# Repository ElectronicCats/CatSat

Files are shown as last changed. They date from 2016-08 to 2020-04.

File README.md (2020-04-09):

# CatSat I

OSHW

**[OSHW] MX0004 | Certified open source hardware |** [oshwa.org/cert.](https://www.oshwa.org/cert)

## Kit CatSat Education

Manual and more information in our [Wiki](https://github.com/ElectronicsCats/CatSat/wiki)

Electronic Cats invests time and resources providing this open source design, please support Electronic Cats and open-source hardware by purchasing products from Electronic Cats!

<a href="https://electroniccats.com/store/catsat/">
  
</a>

Designed by Electronic Cats.

Firmware released under an GNU AGPL v3.0 license. See the LICENSE file for more information.

Hardware released under an CERN Open Hardware Licence v1.2. See the LICENSE_HARDWARE file for more information.

Electronic Cats is a registered trademark, please do not use if you sell these PCBs.

16 July 2016

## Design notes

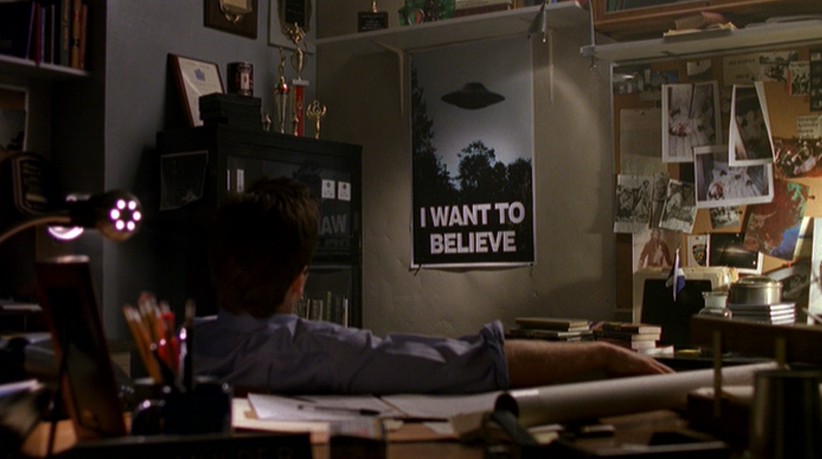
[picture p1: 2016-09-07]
PDF's/MulderNewPoster.jpg

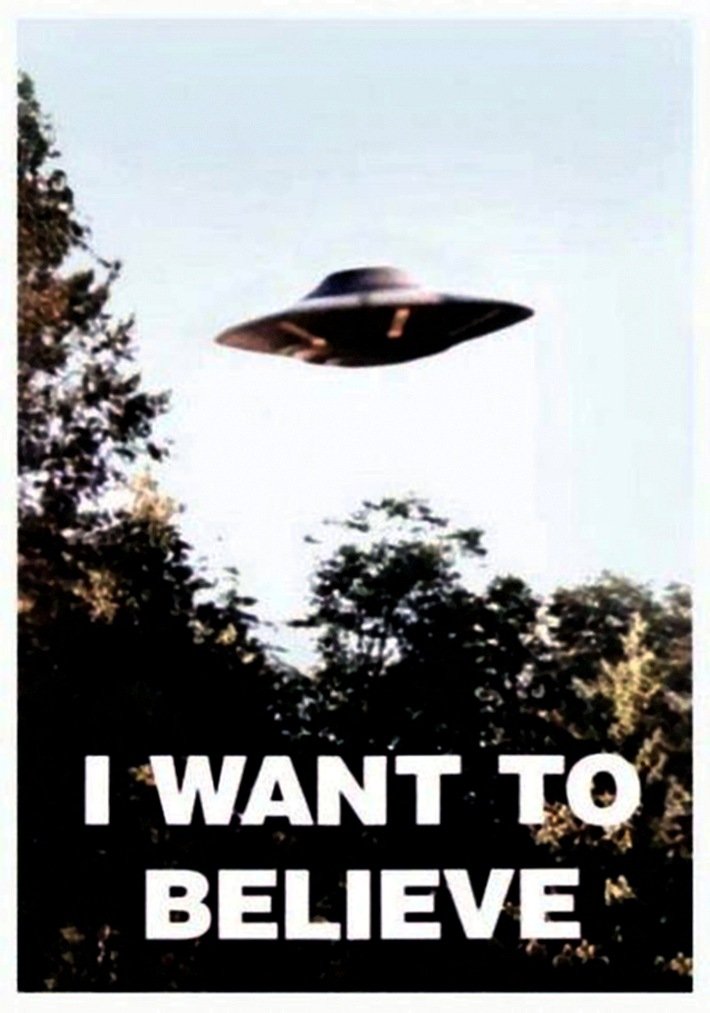
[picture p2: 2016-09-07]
PDF's/xfiles.jpg

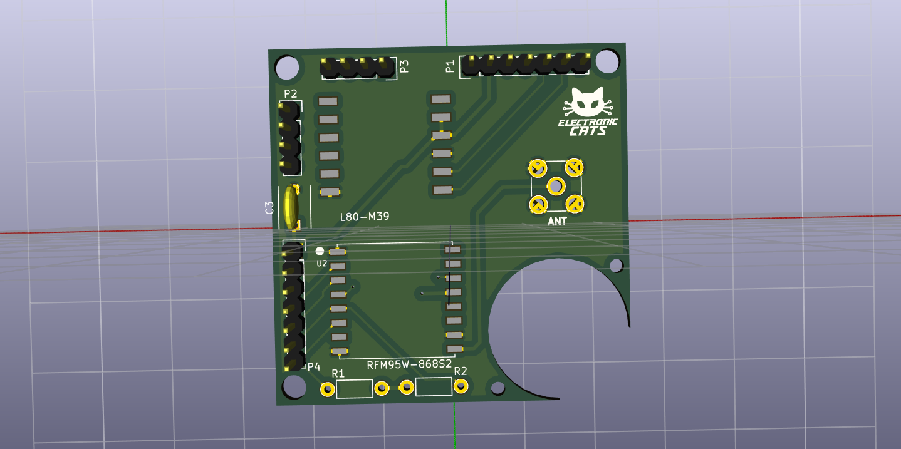
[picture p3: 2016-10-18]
CommunicationBoard/CommunicationBoard.png

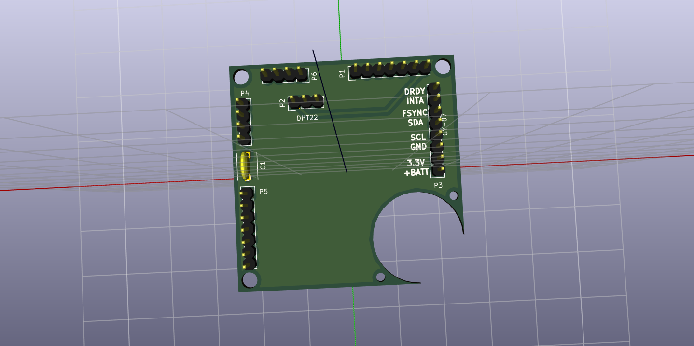
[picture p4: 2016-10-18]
SensorBoard/SensorBoard.png

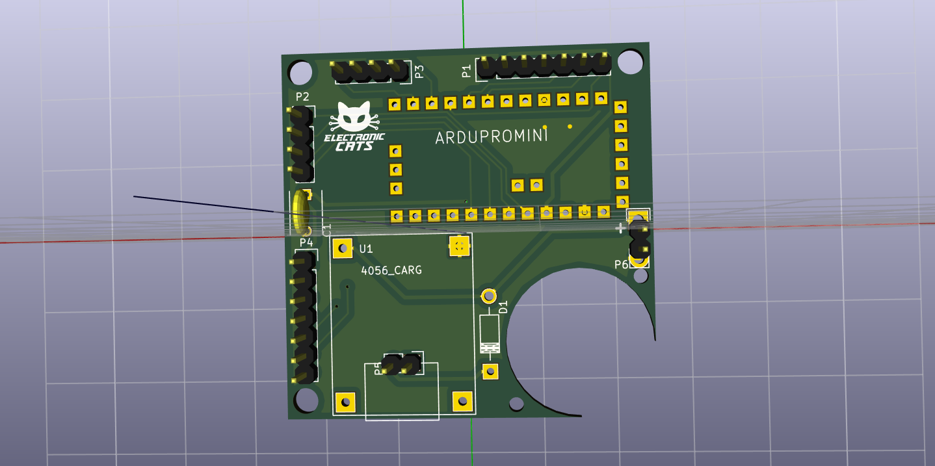
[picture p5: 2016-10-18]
MainBoard/MainBoard.png

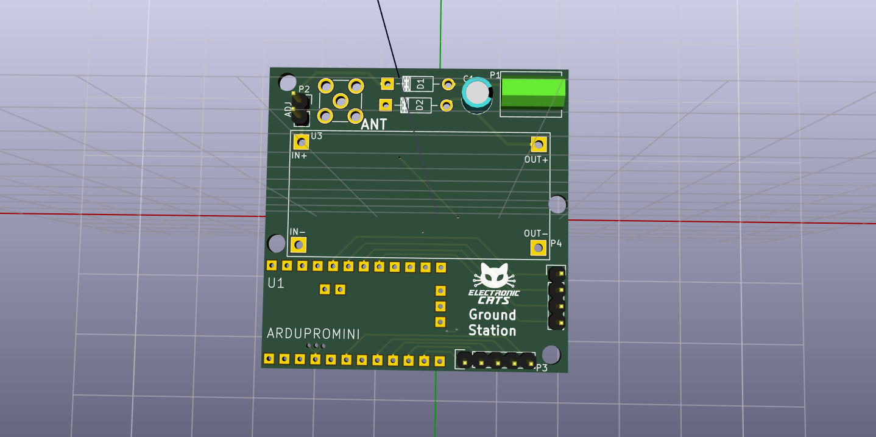
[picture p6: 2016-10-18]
GroundStation/GroundStation.png

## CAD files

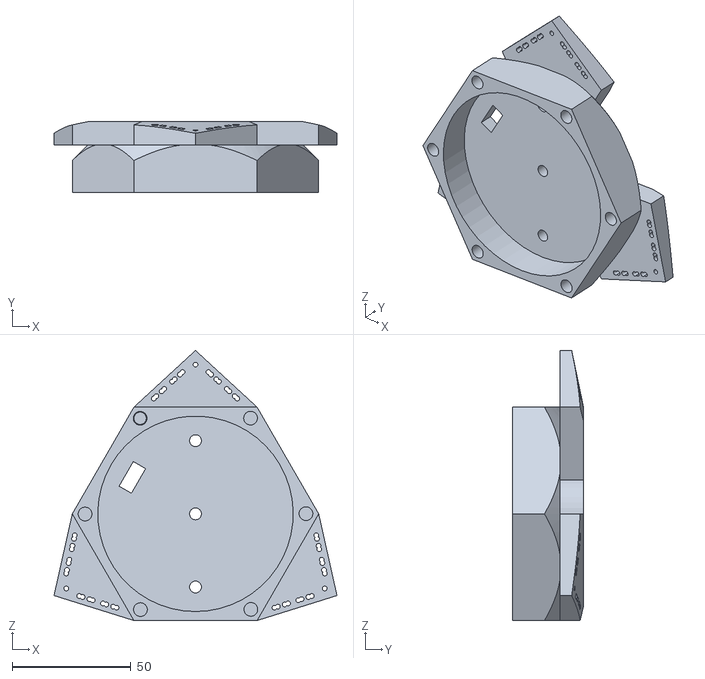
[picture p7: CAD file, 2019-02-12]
caseCatSat1/tapasuperior.STL
119.4 x 30.0 x 113.9

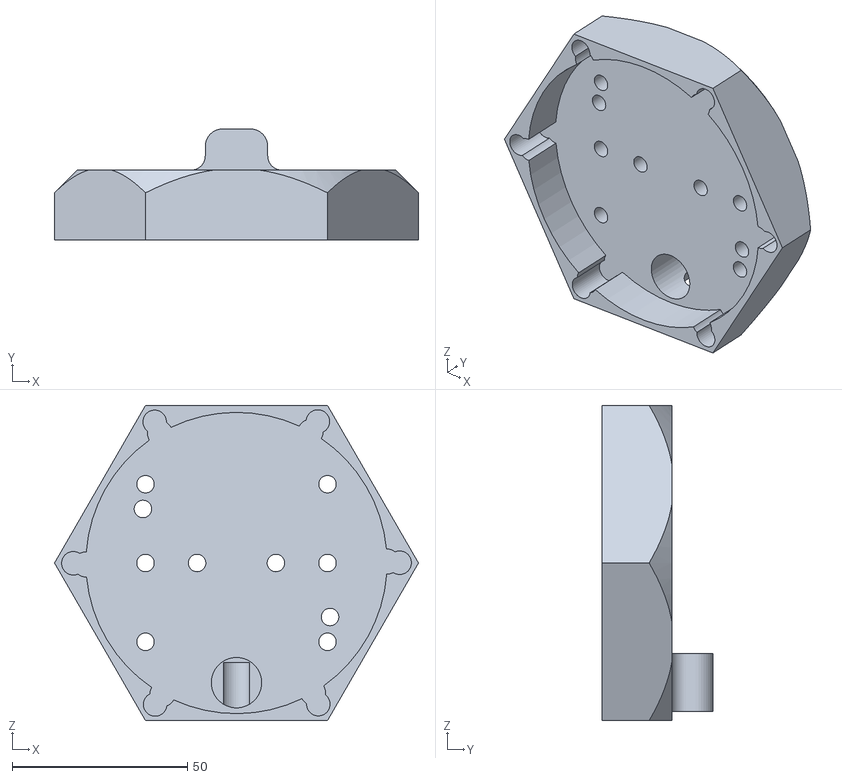
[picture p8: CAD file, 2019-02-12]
caseCatSat1/tapainferior.STL
103.9 x 31.8 x 90.0

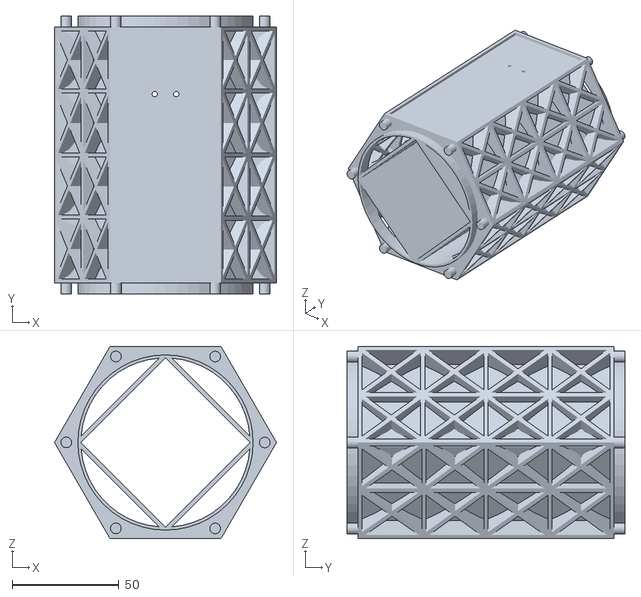
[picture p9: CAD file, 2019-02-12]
caseCatSat1/satelite2.2.STL
103.9 x 130.0 x 90.0

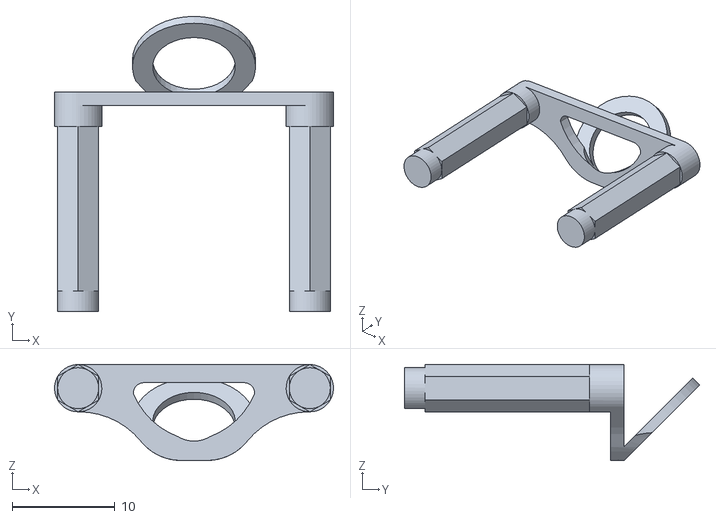
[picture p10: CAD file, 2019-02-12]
caseCatSat1/camarasuport.STL
27.1 x 28.7 x 9.32

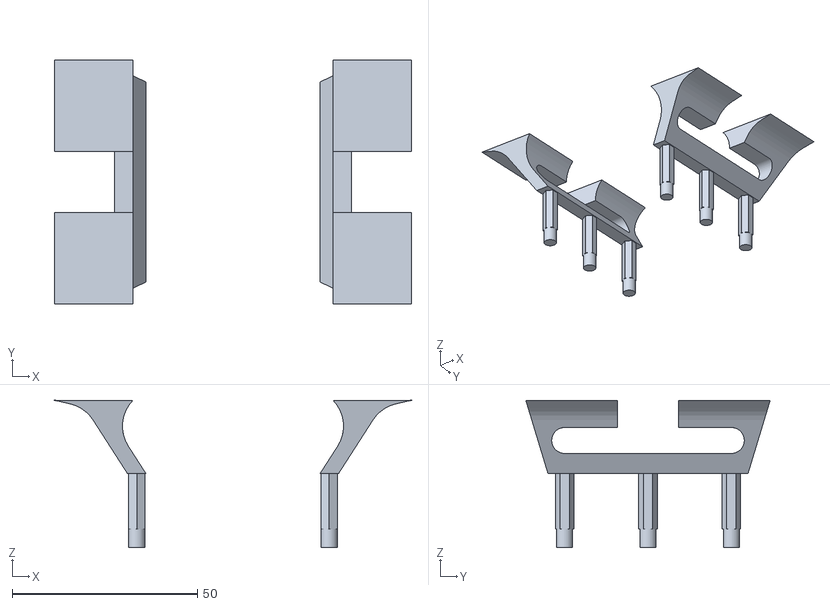
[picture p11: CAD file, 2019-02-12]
caseCatSat1/base.STL
96.4 x 66.0 x 39.8

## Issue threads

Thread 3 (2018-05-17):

Corrección de texto en Wiki

carlosmart7104, 2018-05-17:
04. Vida de la Misión. 4.4 Recuperación, en la frase: "El ingeniero de Sistemas Espaciales deberá disponer de un equipo de recuperación en base a la última información de rastreo emitida por el CanSat..."
Propuesta:
"El ingeniero de Sistemas Espaciales deberá disponer de un equipo de recuperación con base en la última información de rastreo emitida por el CanSat..."
http://www.academia.org.mx/espin/respuestas/item/con-base-en

sabas1080, 2018-08-14:
Muchas gracias @carlosmart7104 , corregido

Closed 2018-08-14.

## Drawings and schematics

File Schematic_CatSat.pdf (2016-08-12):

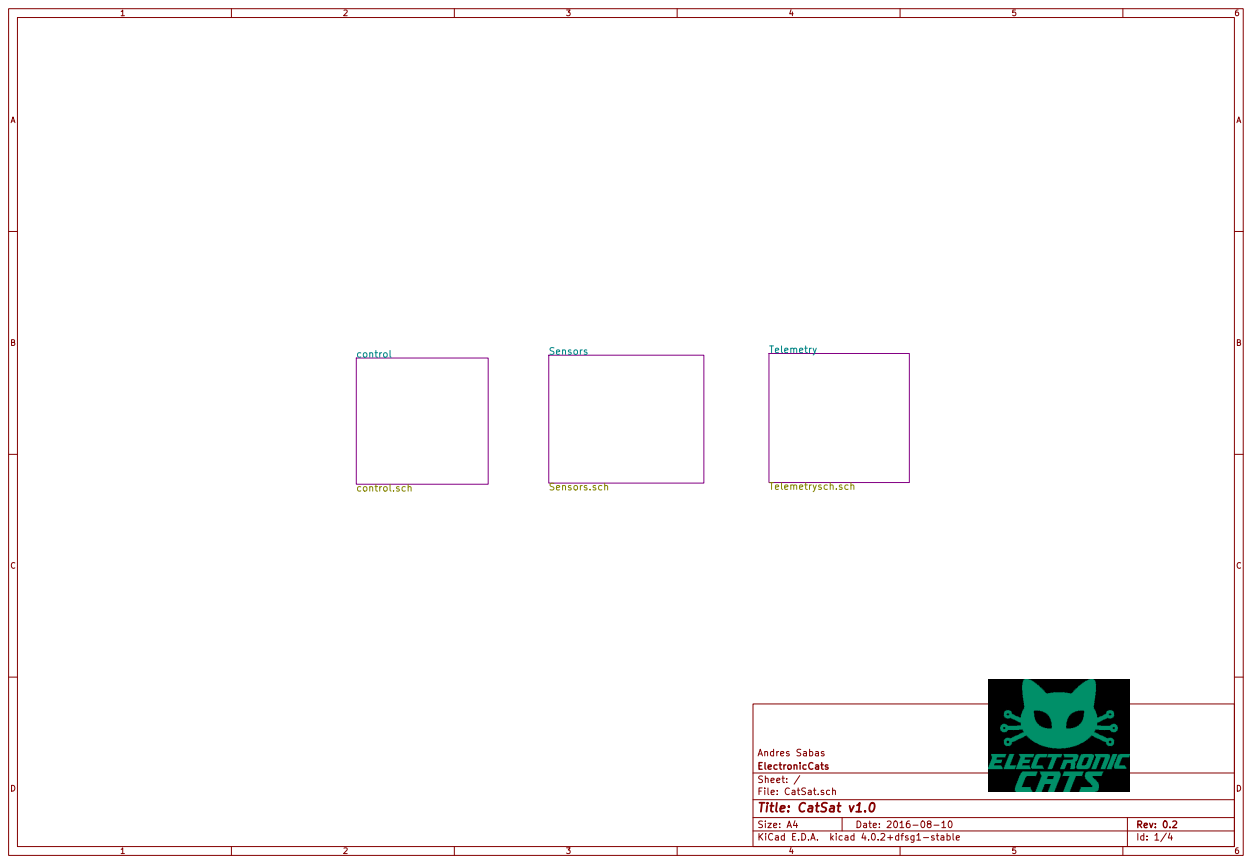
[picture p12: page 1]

File: CatSat.sch Sheet: / ElectronicCats Andres Sabas

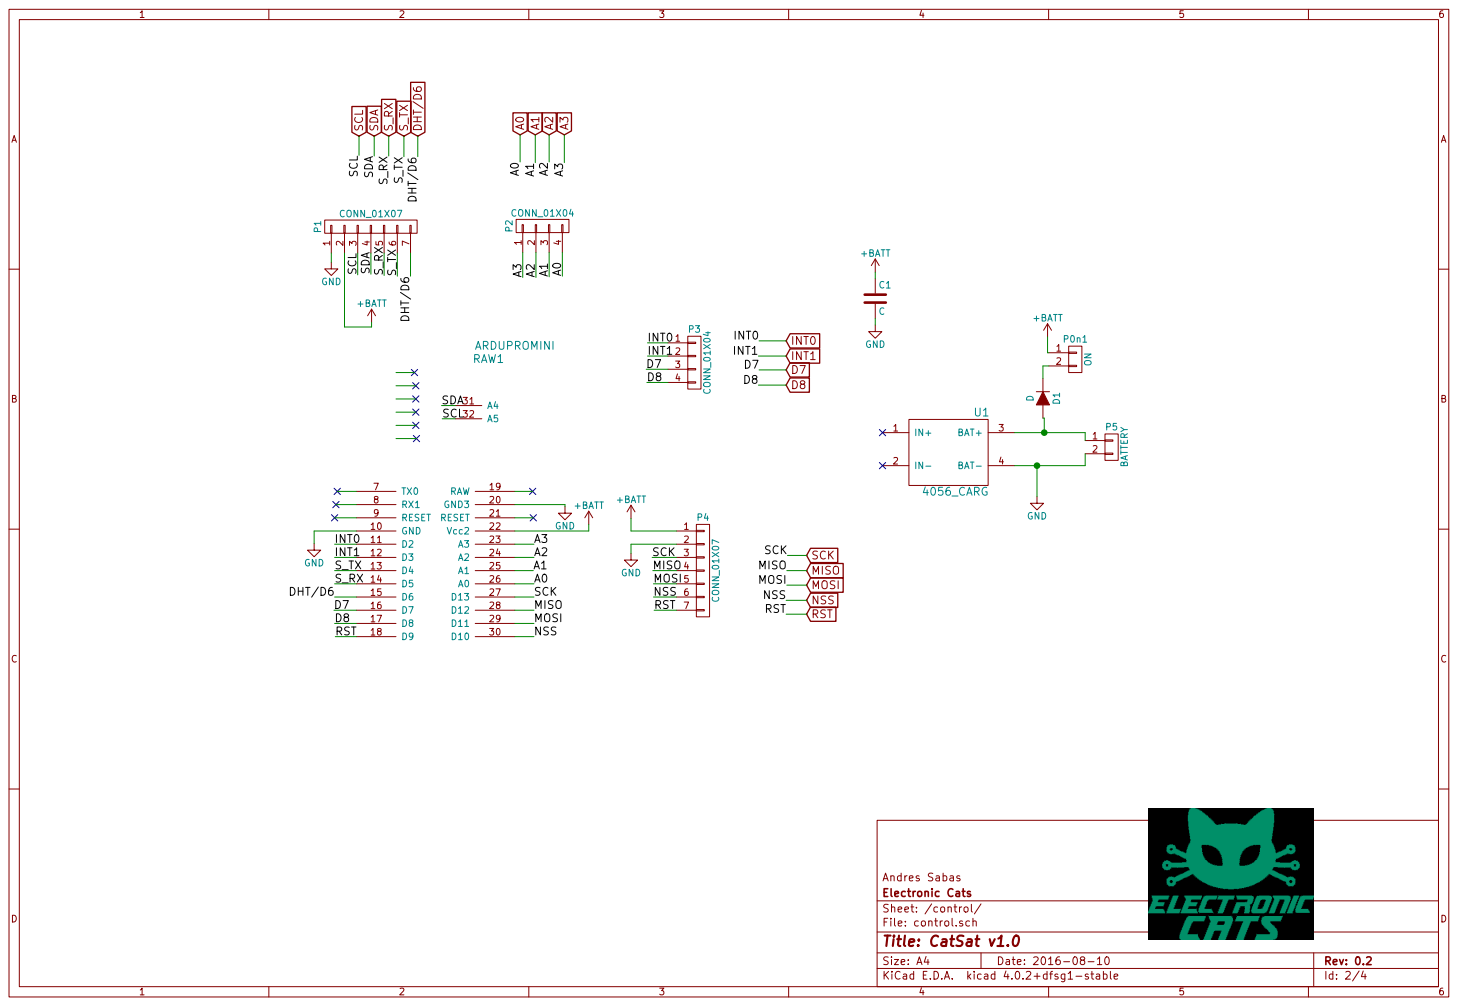
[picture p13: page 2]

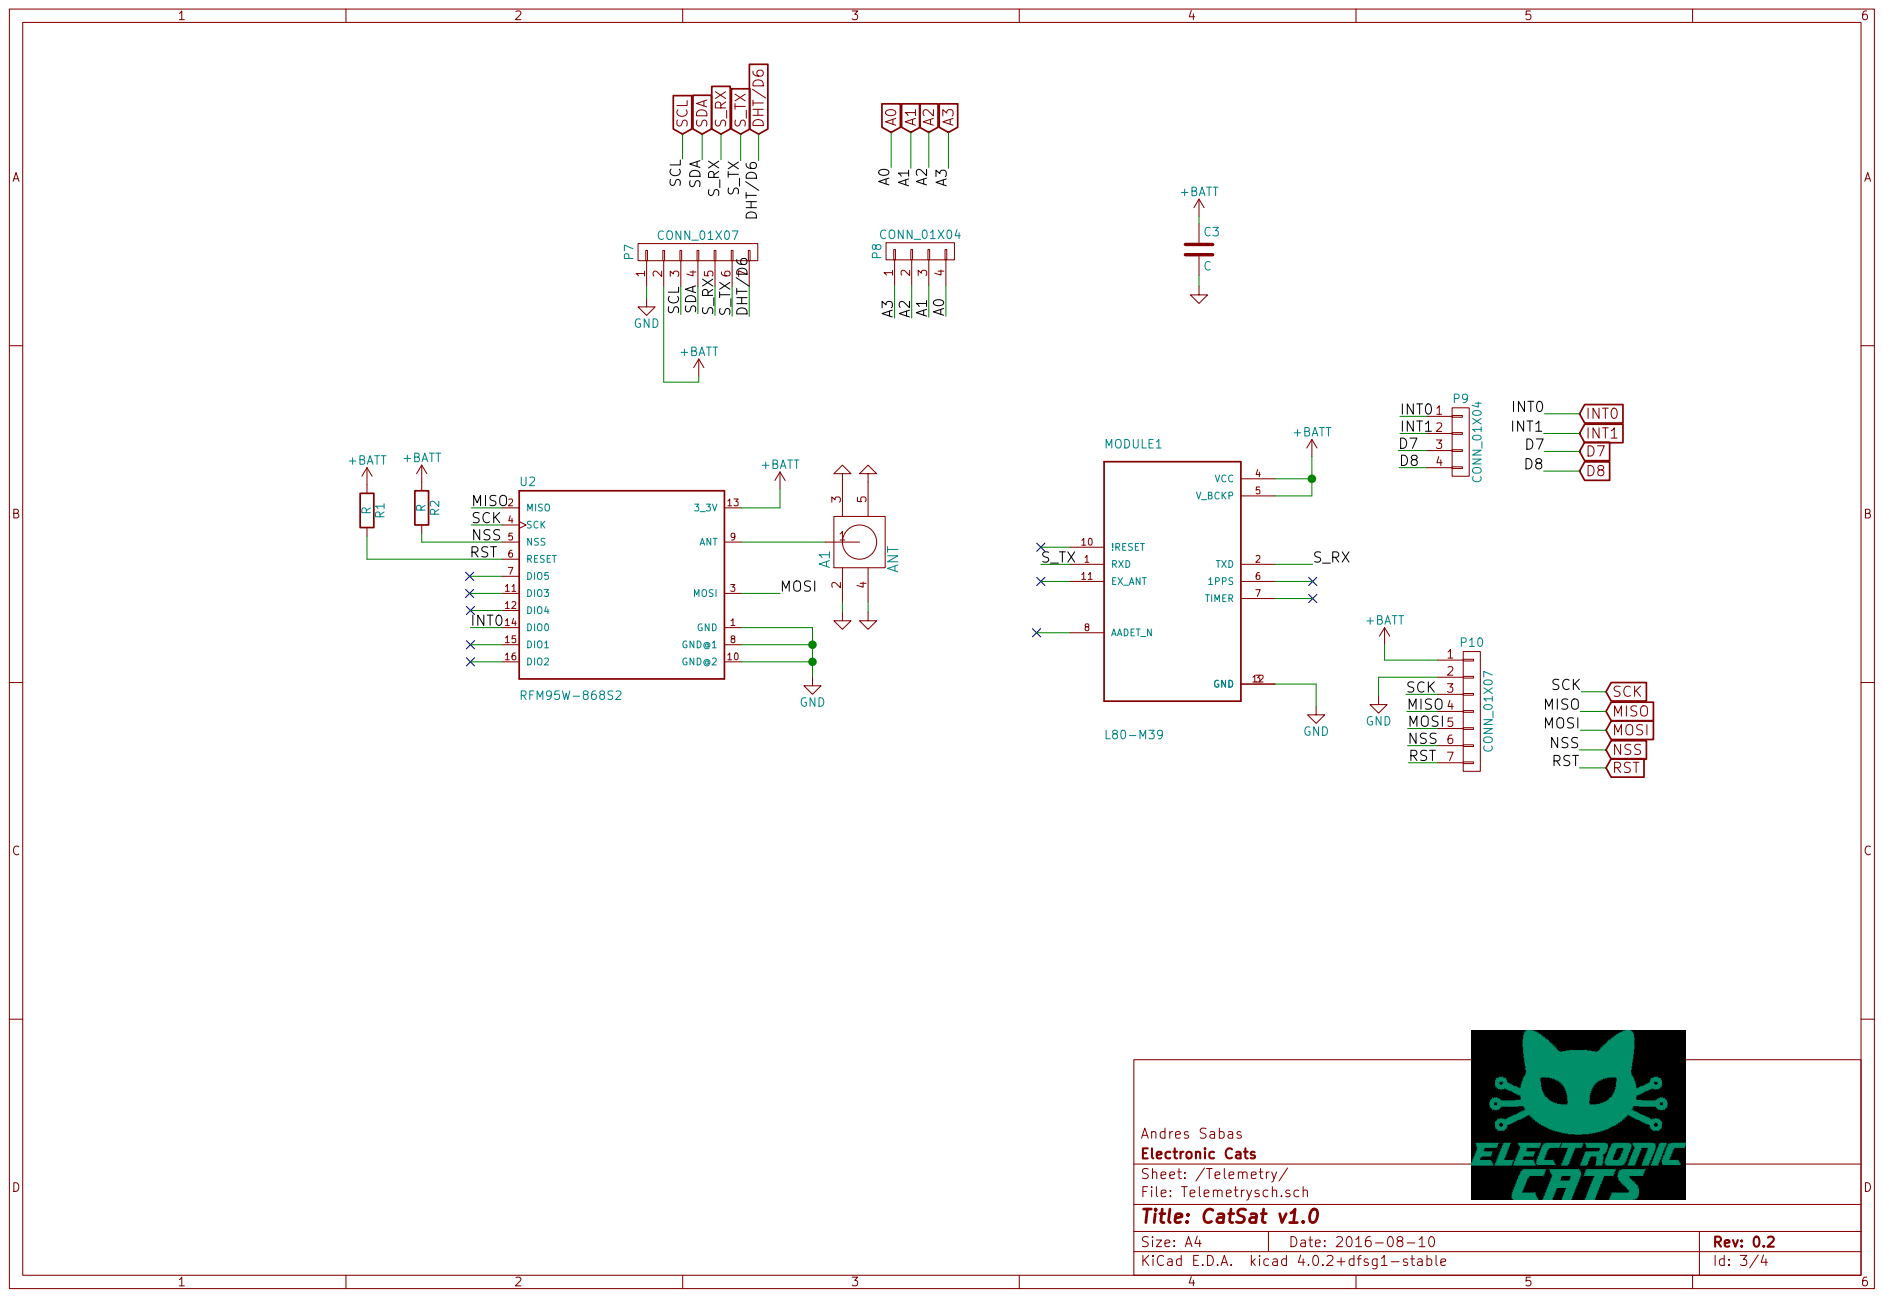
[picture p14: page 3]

7 P7 CONN_01X07 +BATT SCL SDA S_RX S_TX DHT/D6 A3A2A1A0 GND RST

Sheet: /Telemetry/ Electronic Cats Andres Sabas

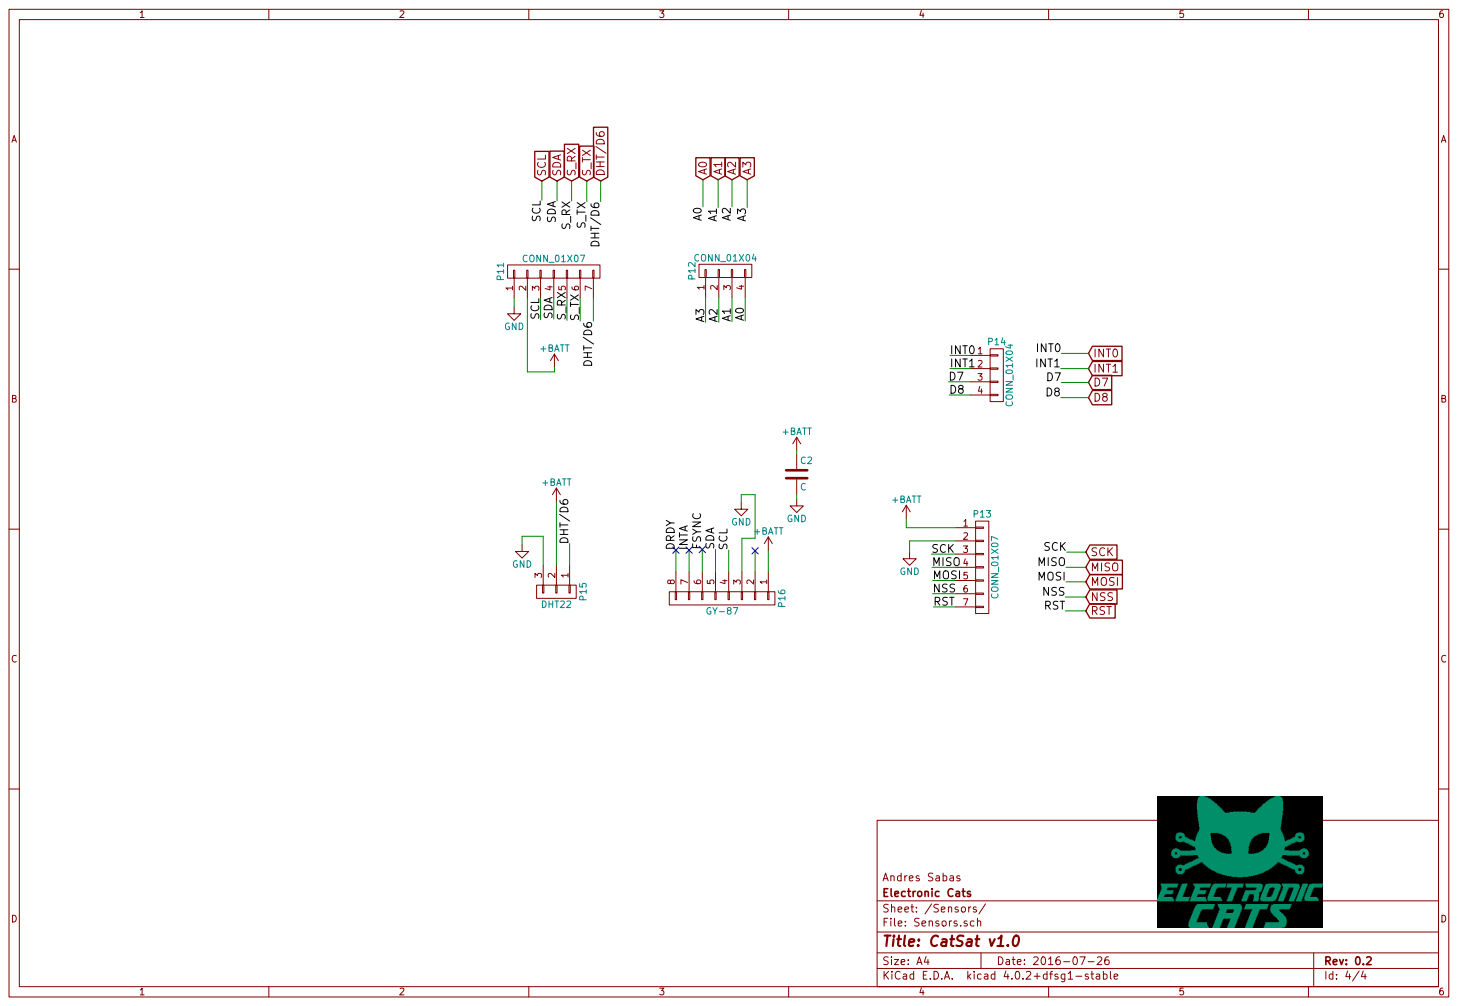
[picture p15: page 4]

File: Sensors.sch Sheet: /Sensors/ Electronic Cats Andres Sabas 1234567 P13 CONN_01X07 1234 P14 CONN_01X04 D8 D7 SCK

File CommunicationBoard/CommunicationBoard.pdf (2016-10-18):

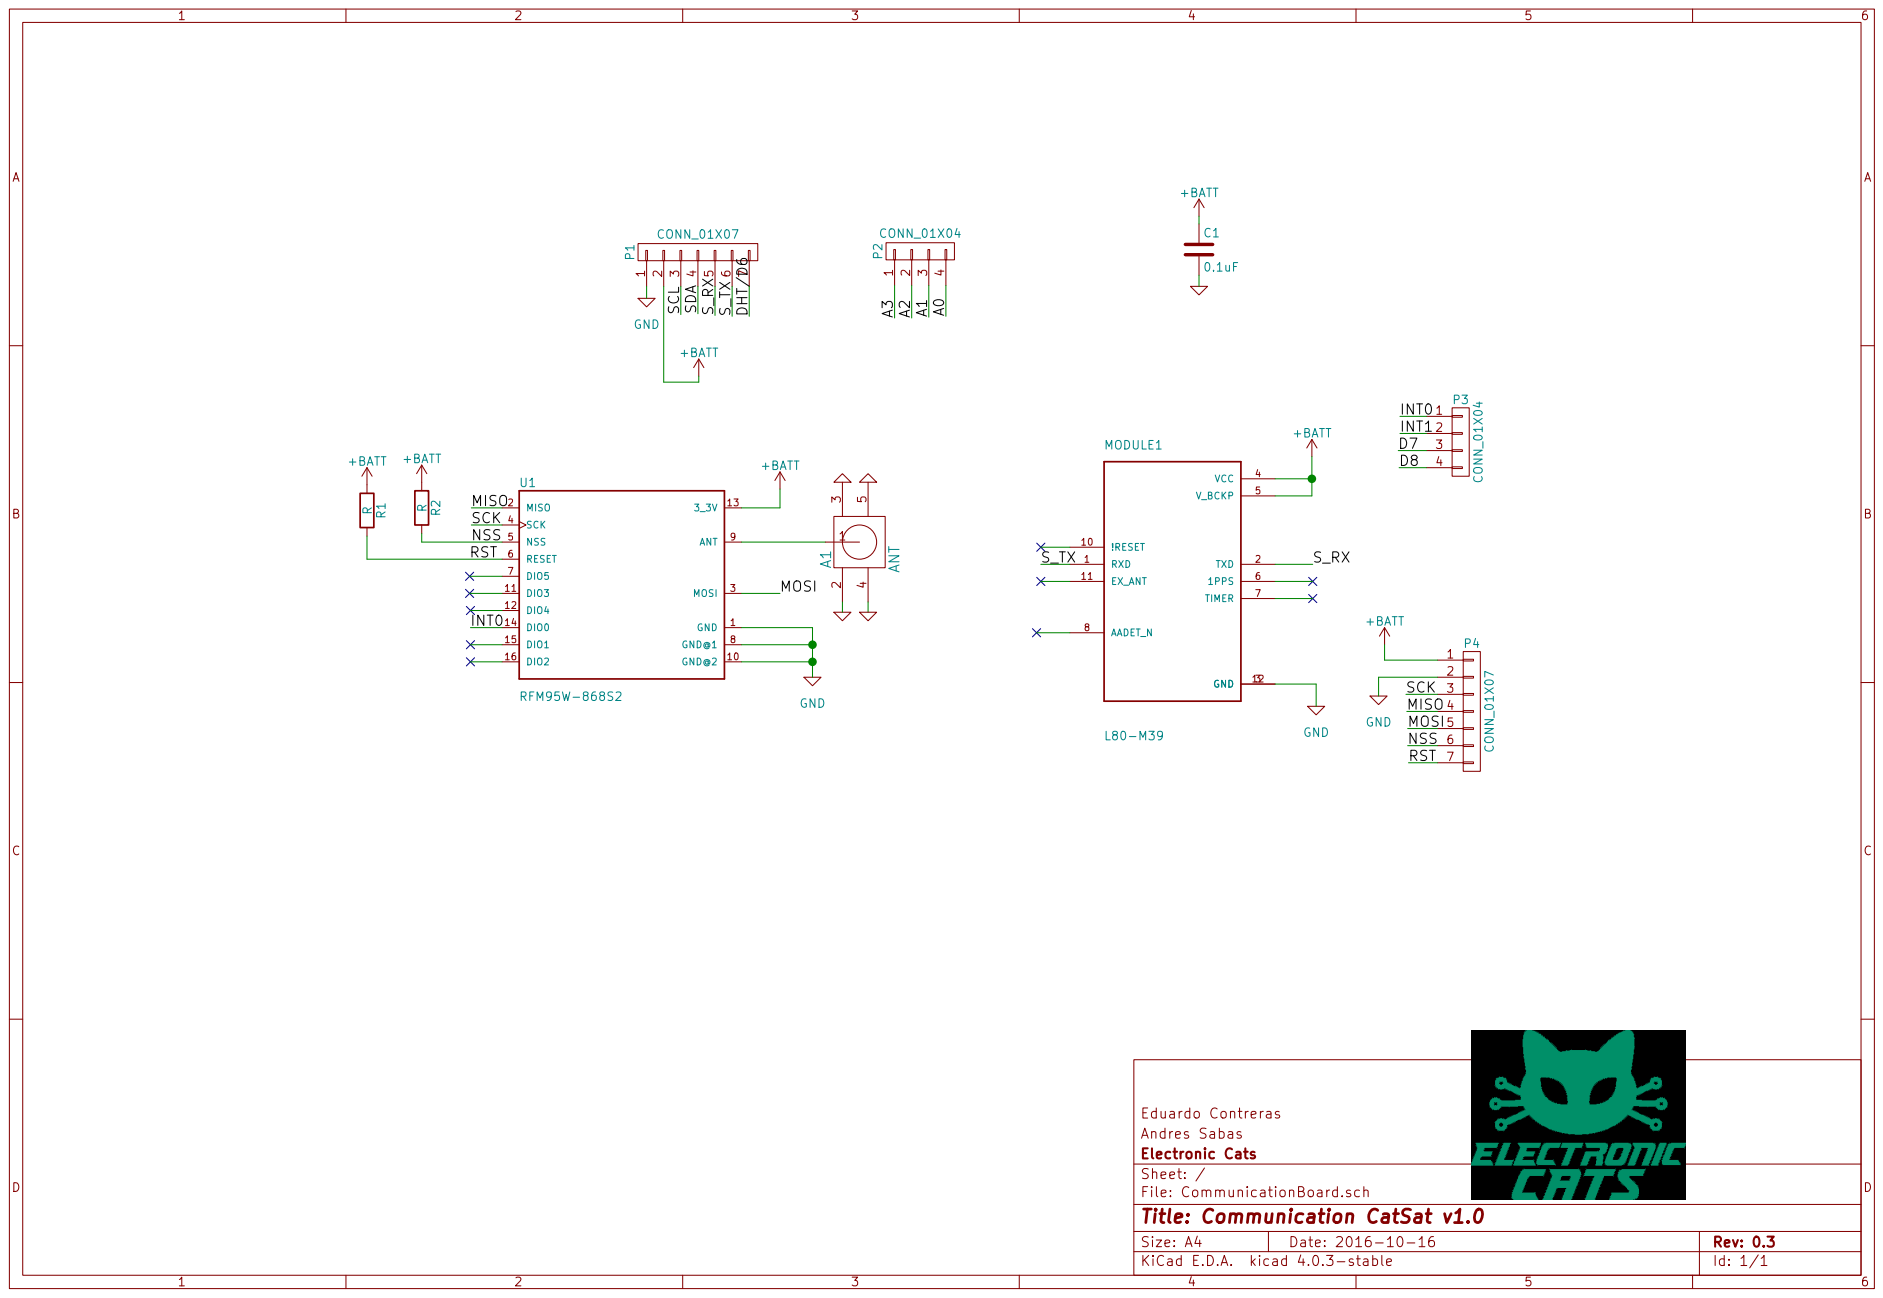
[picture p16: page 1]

7 P1 CONN_01X07 +BATT SCL SDA S_RX S_TX DHT/D6 A3A2A1A0 GND RST

File: CommunicationBoard.sch Sheet: / Electronic Cats Andres Sabas Eduardo Contreras

Id: 1/1 Title: Communication CatSat v1.0

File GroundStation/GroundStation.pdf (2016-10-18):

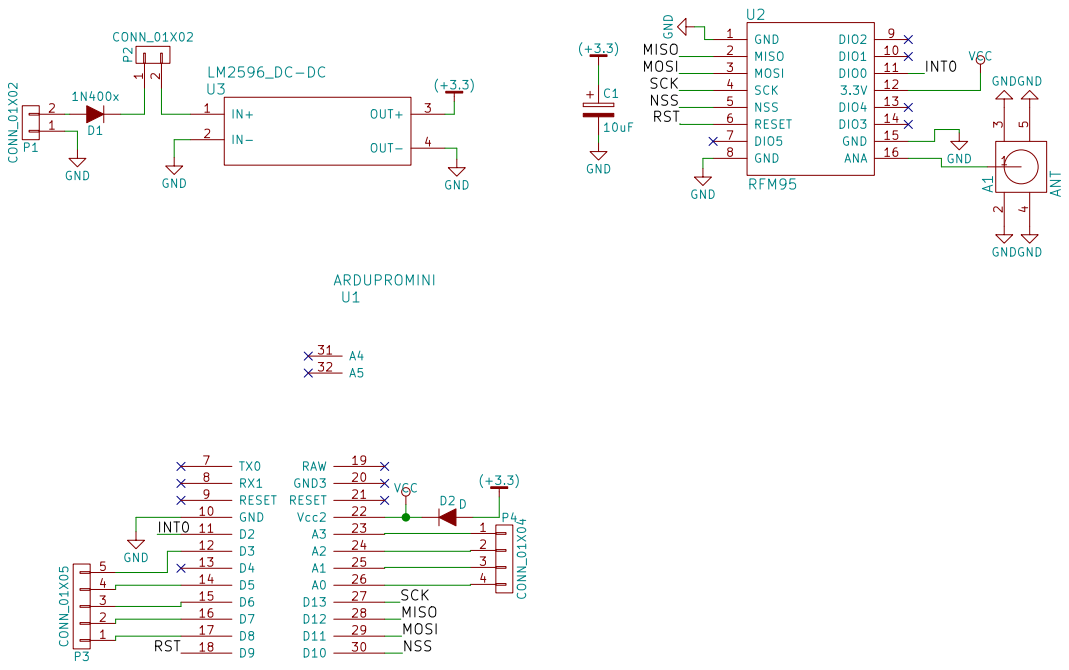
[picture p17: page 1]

2 P2 CONN_01X02 TX0 7 RX1 8 RESET 9 GND 10 GND3 20 D10 30 D2 11 RESET 21 A4 31 D3 12 Vcc2 22 A5 32 D4 13 A3 23 D5 14 A2 24 D6 15 A1 25 D7 16 A0 26 D8 17 D13 27 D9 18 D12 28 RAW 19 D11 29 U1 ARDUPROMINI 1

File: GroundStation.sch Sheet: / Electronic Cats Eduardo Contreras

Id: 1/1 Title: CatSat: Station

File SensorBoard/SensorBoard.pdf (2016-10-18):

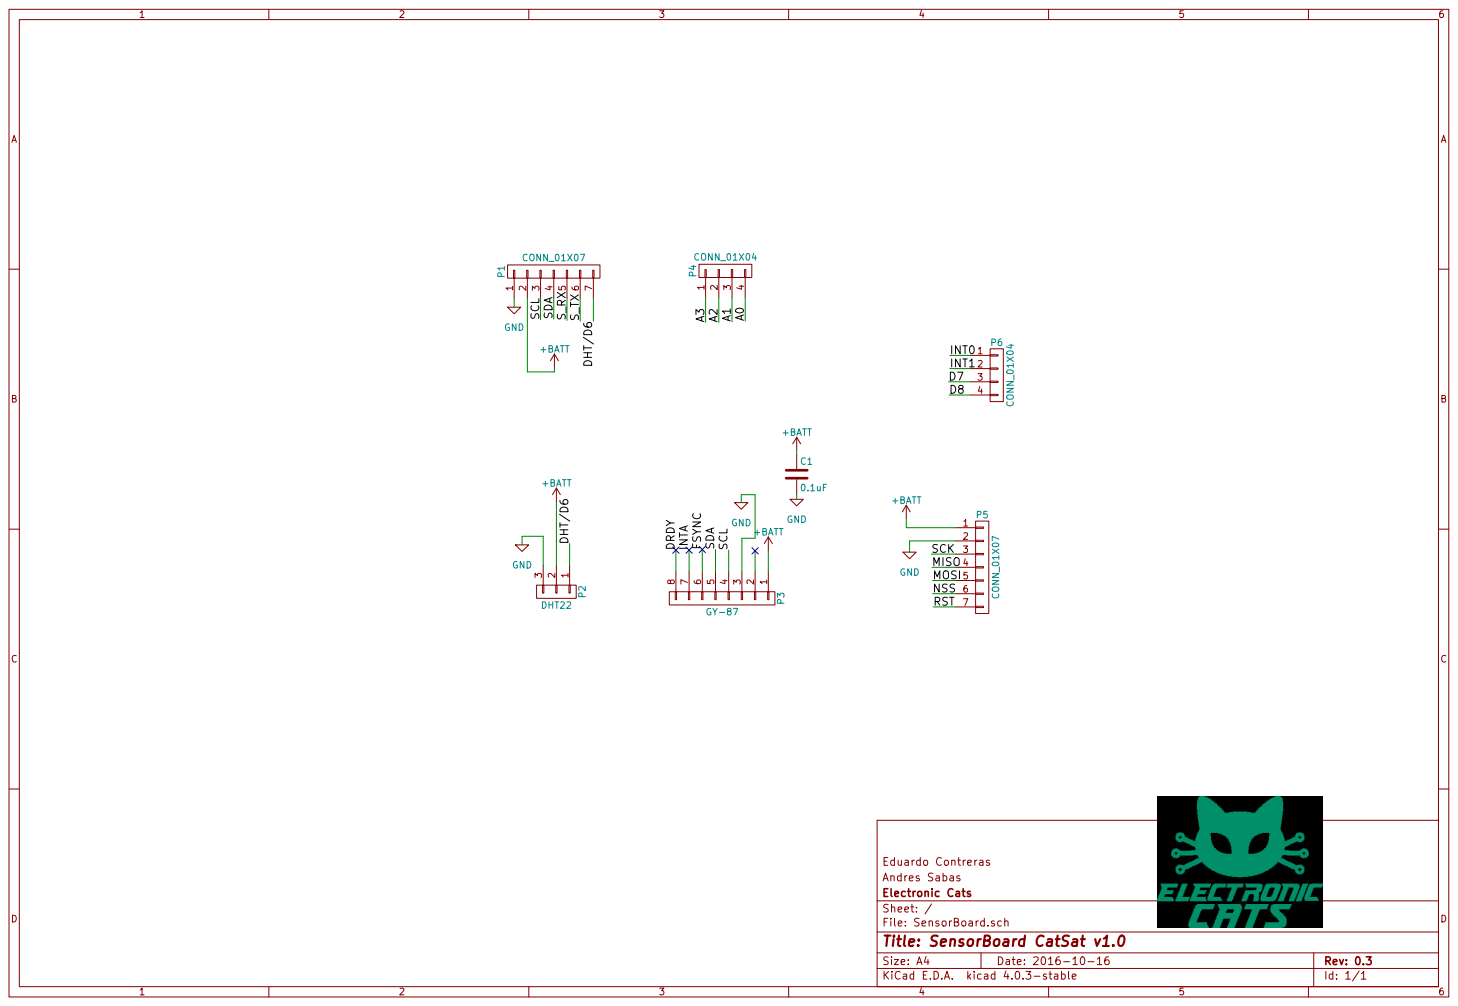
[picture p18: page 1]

File: SensorBoard.sch Sheet: / Electronic Cats Andres Sabas Eduardo Contreras1234567 P5 CONN_01X07 1234 P6 CONN_01X04 D8 D7 SCK

Id: 1/1 Title: SensorBoard CatSat v1.0

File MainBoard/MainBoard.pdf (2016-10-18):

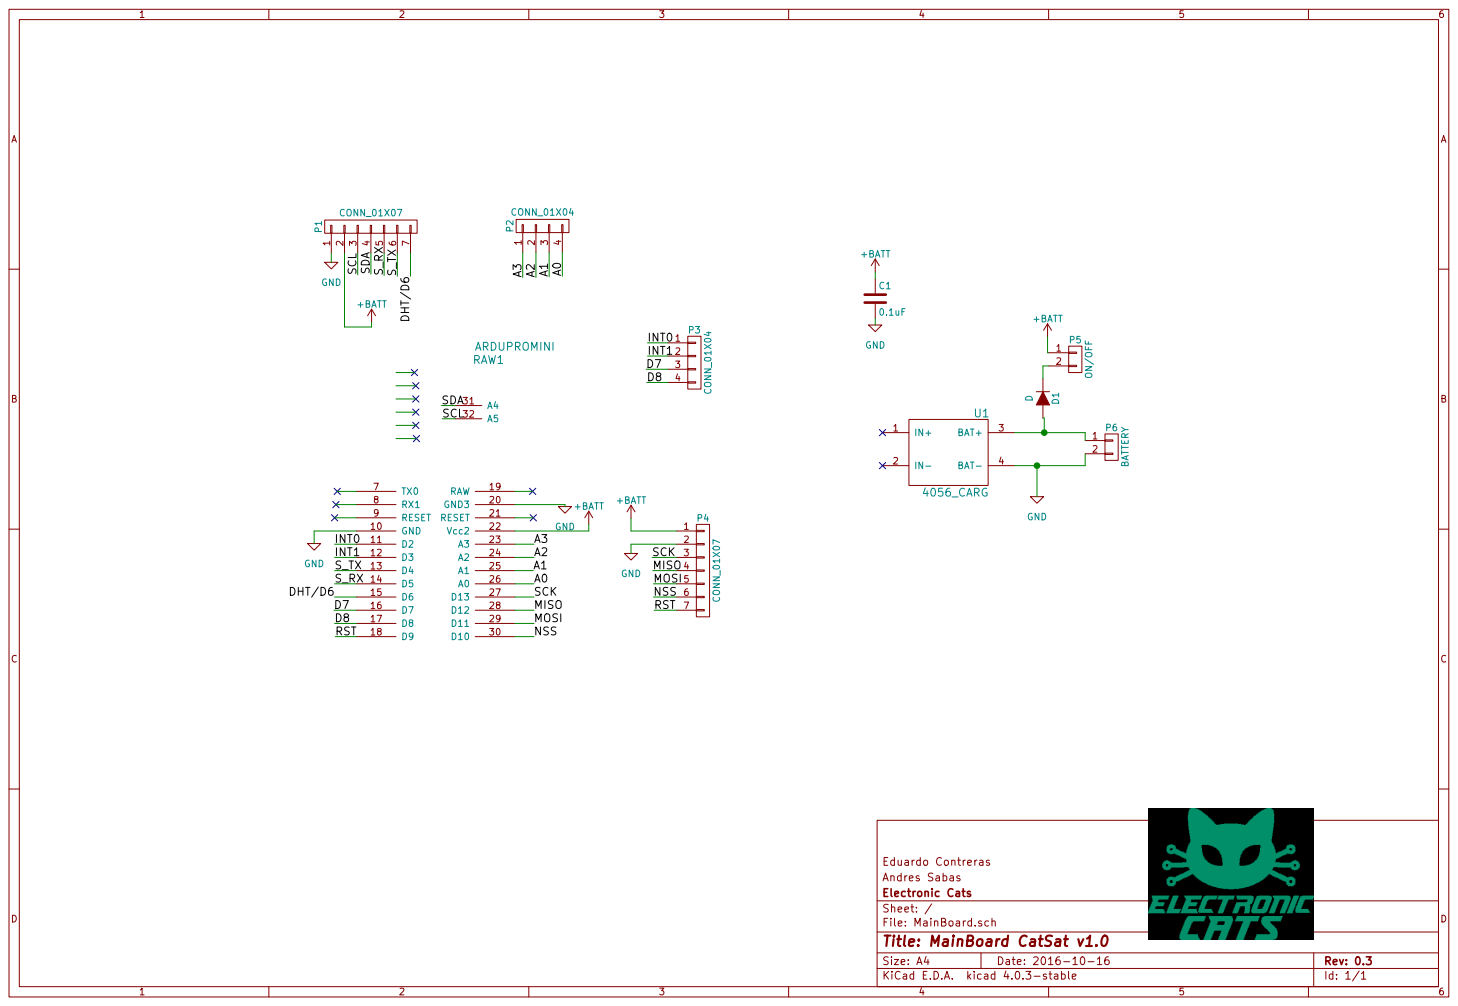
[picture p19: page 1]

Id: 1/1 Title: MainBoard CatSat v1.0

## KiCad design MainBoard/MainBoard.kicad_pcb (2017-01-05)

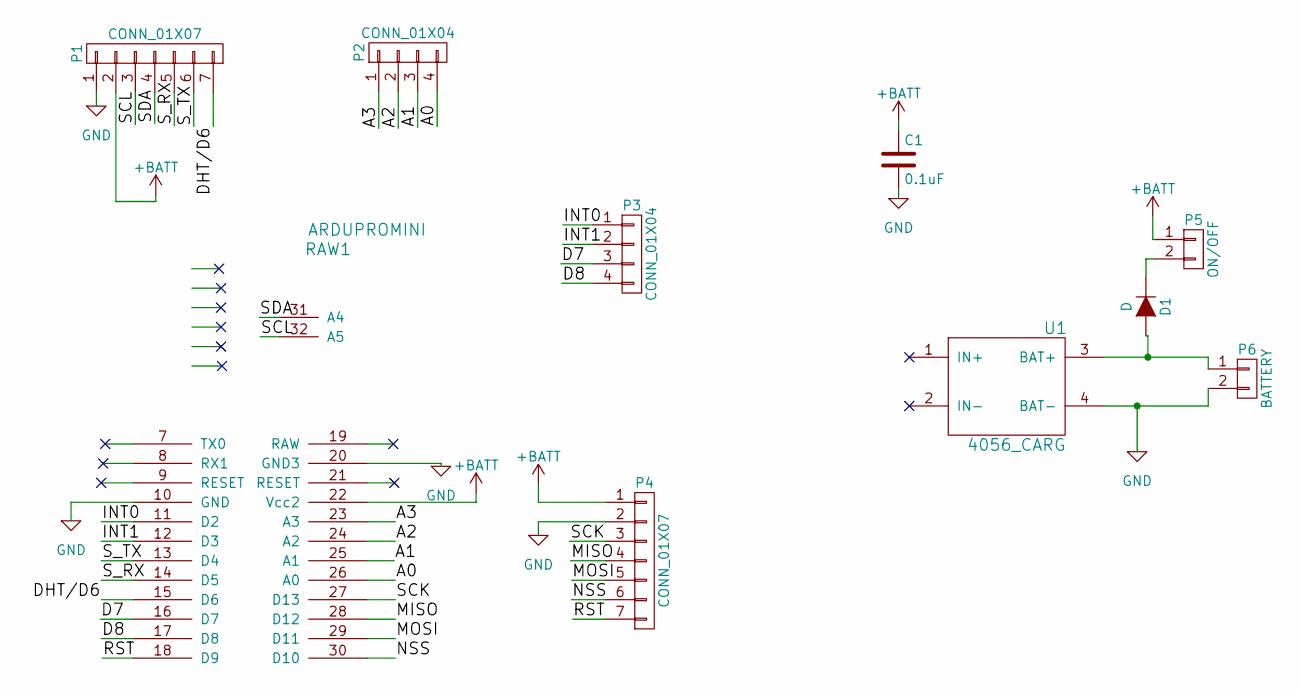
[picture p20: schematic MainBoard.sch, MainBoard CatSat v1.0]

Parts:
C1: 0.1uF; C_Disc_D6_P5
D1: D; Diode_DO-41_SOD81_Horizontal_RM10
P1, P4: CONN_01X07; Pin_Header_Straight_1x07
P2, P3: CONN_01X04; Pin_Header_Straight_1x04
P5: ON/OFF; Pin_Header_Angled_1x02
P6: BATTERY; Pin_Header_Straight_1x02
RAW1: ARDUPROMINI; arduinoMiniPro
U1: 4056_CARG; 4056_lipoCharg

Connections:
+BATT: C1.1, P1.2, P4.1, P5.1, RAW1.22 (Vcc2)
/A0: P2.4, RAW1.26 (A0)
/A1: P2.3, RAW1.25 (A1)
/A2: P2.2, RAW1.24 (A2)
/A3: P2.1, RAW1.23 (A3)
/D7: P3.3, RAW1.16 (D7)
/D8: P3.4, RAW1.17 (D8)
/DHT/D6: P1.7, RAW1.15 (D6)
/INT0: P3.1, RAW1.11 (D2)
/INT1: P3.2, RAW1.12 (D3)
/MISO: P4.4, RAW1.28 (D12)
/MOSI: P4.5, RAW1.29 (D11)
/NSS: P4.6, RAW1.30 (D10)
/RST: P4.7, RAW1.18 (D9)
/SCK: P4.3, RAW1.27 (D13)
/SCL: P1.3, RAW1.32 (A5)
/SDA: P1.4, RAW1.31 (A4)
/S_RX: P1.5, RAW1.14 (D5)
/S_TX: P1.6, RAW1.13 (D4)
GND: C1.2, P1.1, P4.2, P6.2, RAW1.10 (GND), RAW1.20 (GND3), U1.4 (BAT-)
unnamed: D1.1 (K), P5.2
unnamed: D1.2 (A), P6.1, U1.3 (BAT+)

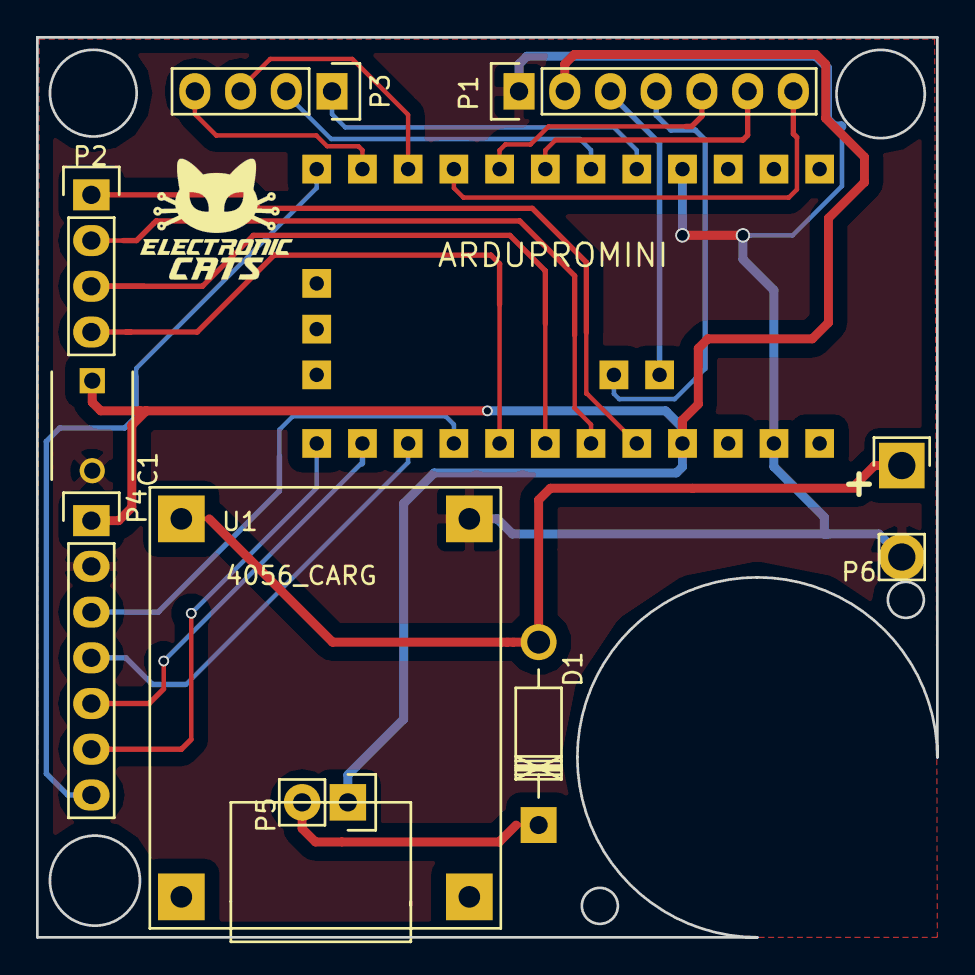
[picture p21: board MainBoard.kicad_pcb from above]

Board: 2 copper layers, 50.0 x 50.0 mm, 10 parts (0 on the bottom side), 22 nets.

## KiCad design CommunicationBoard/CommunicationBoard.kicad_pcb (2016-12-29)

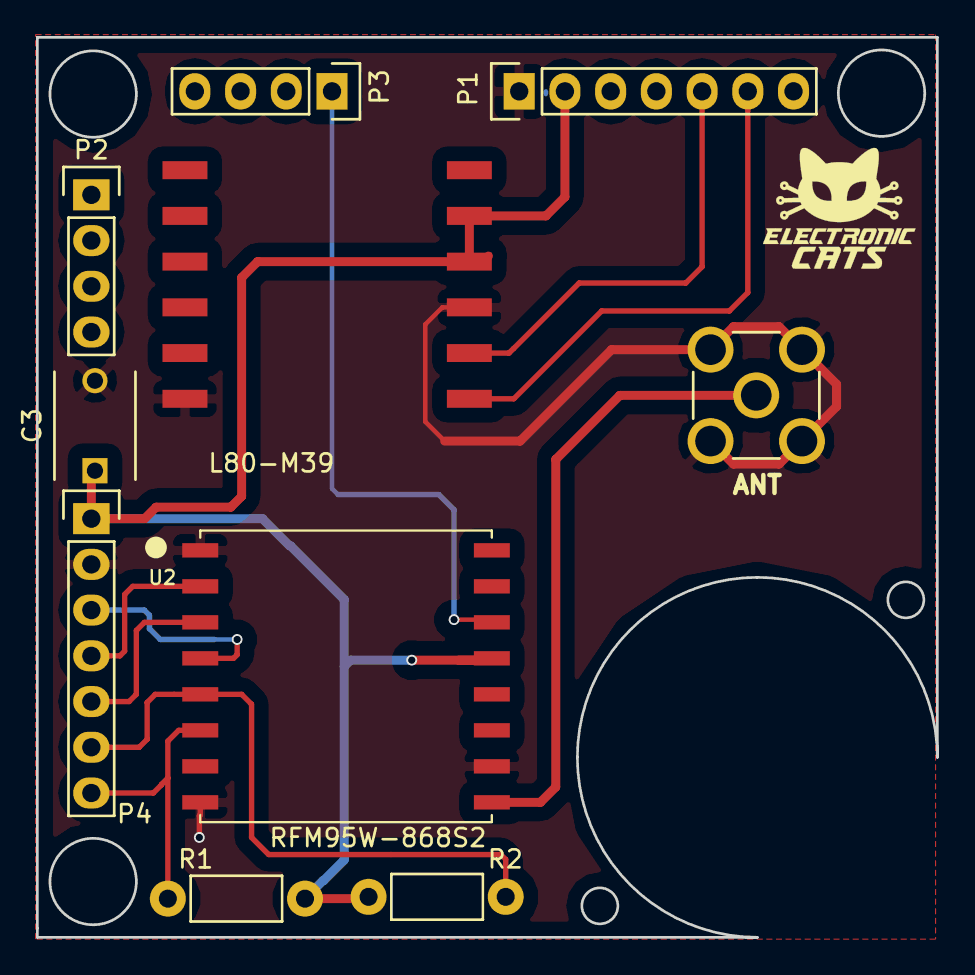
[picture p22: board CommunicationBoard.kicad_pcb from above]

Board: 2 copper layers, 50.0 x 50.0 mm, 10 parts (0 on the bottom side), 11 nets.

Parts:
A1: ANT; AMPHENOL_901-144
C3: C; C_Disc_D6_P5
MODULE1: L80-M39; L80
P1, P4: CONN_01X07; Pin_Header_Straight_1x07
P2, P3: CONN_01X04; Pin_Header_Straight_1x04
R1, R2: R; Resistor_Horizontal_RM7mm
U2: RFM95W-868S2; RFM

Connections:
+BATT: C3.1, MODULE1.4, MODULE1.5, P1.2, P4.1, R1.1, R2.1, U2.13
GND: A1.2, A1.3, A1.4, A1.5, C3.2, MODULE1.3, MODULE1.12, P1.1, P4.2, U2.1, U2.8, U2.10
INT0: P3.1, U2.14
MISO: P4.4, U2.2
MOSI: P4.5, U2.3
NSS: P4.6, R2.2, U2.5
unnamed: A1.1, U2.9
RST: P4.7, R1.2, U2.6
SCK: P4.3, U2.4
S_RX: MODULE1.2, P1.5
S_TX: MODULE1.1, P1.6

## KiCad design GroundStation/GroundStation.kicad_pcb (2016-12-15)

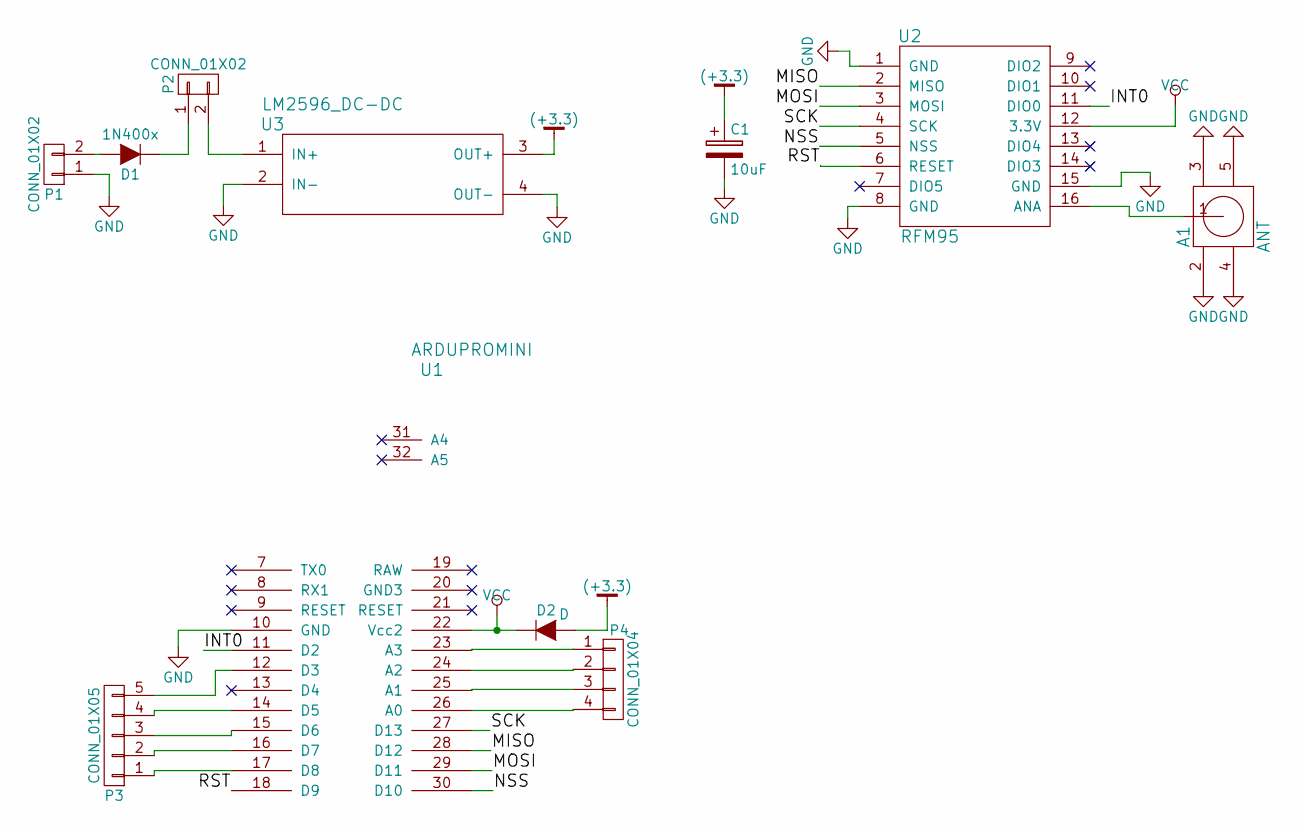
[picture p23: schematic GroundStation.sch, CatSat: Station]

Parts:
A1: ANT; AMPHENOL_901-144
C1: 10uF; C_Radial_D5_L6_P2.5
D1: 1N400x; Diode_DO-41_SOD81_Horizontal_RM10
D2: D; Diode_DO-41_SOD81_Horizontal_RM10
P1: CONN_01X02; bornier2
P2: CONN_01X02; Pin_Header_Straight_1x02
P3: CONN_01X05
P4: CONN_01X04
U1: ARDUPROMINI; arduinoMiniPro2
U2: RFM95; RFM
U3: LM2596_DC-DC; LM2596DC-DC

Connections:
(+3.3): C1.1, D2.2 (A), U3.3 (OUT+)
/INT0: U1.11 (D2), U2.11 (DIO0)
/MISO: U1.28 (D12), U2.2 (MISO)
/MOSI: U1.29 (D11), U2.3 (MOSI)
/NSS: U1.30 (D10), U2.5 (NSS)
/RST: U1.18 (D9), U2.6 (RESET)
/SCK: U1.27 (D13), U2.4 (SCK)
GND: A1.2, A1.3, A1.4, A1.5, C1.2, P1.1, U1.10 (GND), U2.1 (GND), U2.8 (GND), U2.15 (GND), U3.2 (IN-), U3.4 (OUT-)
unnamed: A1.1, U2.16 (ANA)
unnamed: D1.1 (K), P2.1
unnamed: D1.2 (A), P1.2
unnamed: P2.2, U3.1 (IN+)
unnamed: P3.1, U1.17 (D8)
unnamed: P3.2, U1.16 (D7)
unnamed: P3.3, U1.15 (D6)
unnamed: P3.4, U1.14 (D5)
unnamed: P3.5, U1.12 (D3)
unnamed: P4.1, U1.23 (A3)
unnamed: P4.2, U1.24 (A2)
unnamed: P4.3, U1.25 (A1)
unnamed: P4.4, U1.26 (A0)
VCC: D2.1 (K), U1.22 (Vcc2), U2.12 (3.3V)

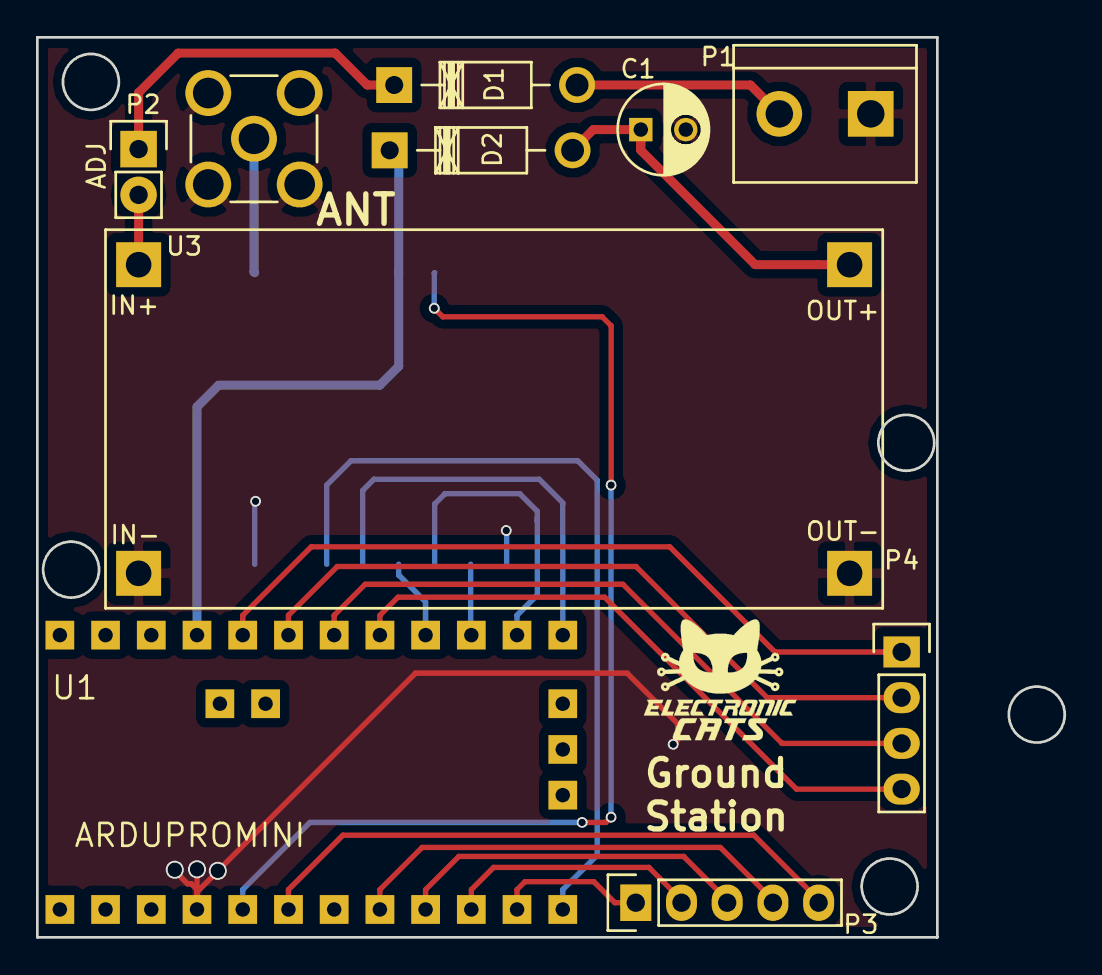
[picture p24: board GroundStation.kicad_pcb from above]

Board: 2 copper layers, 50.0 x 50.0 mm, 11 parts (1 on the bottom side), 22 nets.

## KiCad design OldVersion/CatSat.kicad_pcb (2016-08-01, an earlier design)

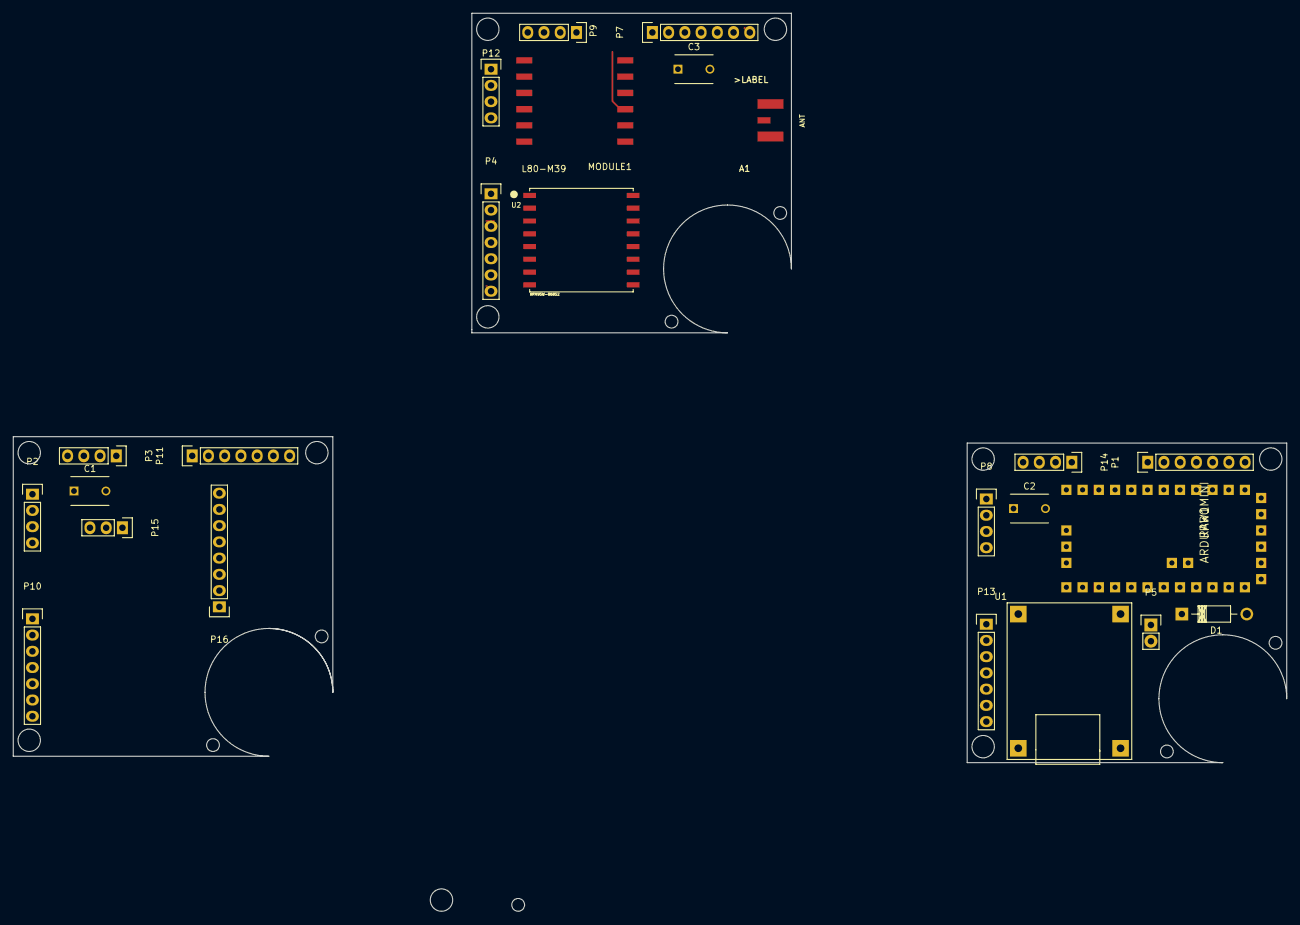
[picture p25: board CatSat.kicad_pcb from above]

Board: 2 copper layers, 199.2 x 140.5 mm, 24 parts (0 on the bottom side), 23 nets.

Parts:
A1: ANT; SMA_Conn_Ant
C1, C2, C3: C; C_Disc_D6_P5
D1: D; Diode_DO-41_SOD81_Horizontal_RM10
MODULE1: L80-M39; L80
P1, P4, P7, P10, P11, P13: CONN_01X07; Pin_Header_Straight_1x07
P2, P3, P8, P9, P12, P14: CONN_01X04; Pin_Header_Straight_1x04
P5: BATTERY; Pin_Header_Straight_1x02
P15: DHT22; Pin_Header_Straight_1x03
P16: GY-87; Pin_Header_Straight_1x08
RAW1: ARDUPROMINI; arduinoMiniPro
U1: 4056_CARG; 4056_lipoCharg
U2: RFM95W-868S2; RFM

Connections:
+BATT: C1.1, C2.1, C3.1, D1.1, MODULE1.4, P1.2, P4.1, P7.2, P10.1, P11.2, P13.1, P15.2, P16.1, RAW1.22, U2.13
A0: P2.4, P8.4, P12.4, RAW1.26
A1: P2.3, P8.3, P12.3, RAW1.25
A2: P2.2, P8.2, P12.2, RAW1.24
A3: P2.1, P8.1, P12.1, RAW1.23
D7: P3.3, P9.3, P14.3, RAW1.16
D8: P3.4, P9.4, P14.4, RAW1.17
DHT/D6: P1.7, P7.7, P11.7, P15.1, RAW1.15
GND: A1.1, A1.3, C1.2, C2.2, C3.2, MODULE1.3, MODULE1.12, P1.1, P4.2, P7.1, P10.2, P11.1, P13.2, P15.3, P16.2, RAW1.10, RAW1.20, U2.1, U2.8, U2.10
INT0: P3.1, P9.1, P14.1, RAW1.11, U2.14
INT1: P3.2, P9.2, P14.2, RAW1.12
MISO: P4.4, P10.4, P13.4, RAW1.28, U2.2
MOSI: P4.5, P10.5, P13.5, RAW1.29, U2.3
NSS: P4.6, P10.6, P13.6, RAW1.30, U2.5
unnamed: A1.2, U2.9
unnamed: D1.2, P5.1, U1.3
unnamed: P5.2, U1.4
RST: P4.7, P10.7, P13.7, RAW1.18, U2.6
SCK: P4.3, P10.3, P13.3, RAW1.27, U2.4
SCL: P1.3, P7.3, P11.3, P16.4, RAW1.32
SDA: P1.4, P7.4, P11.4, P16.5, RAW1.31
S_RX: MODULE1.2, P1.5, P7.5, P11.5, RAW1.14
S_TX: MODULE1.1, P1.6, P7.6, P11.6, RAW1.13

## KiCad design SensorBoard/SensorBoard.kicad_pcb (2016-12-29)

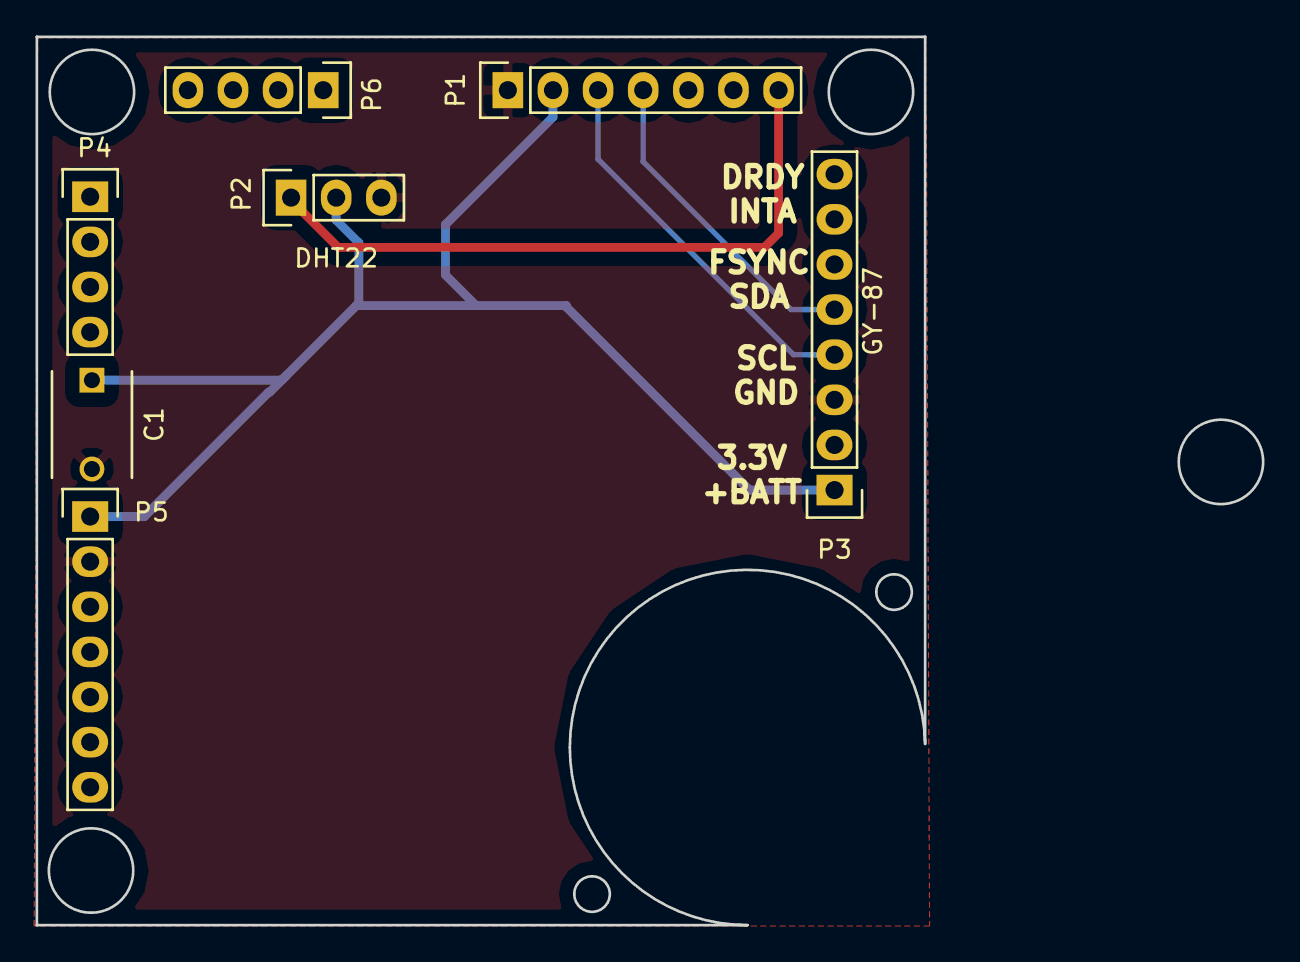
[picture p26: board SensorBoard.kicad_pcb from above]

Board: 2 copper layers, 50.0 x 50.0 mm, 7 parts (0 on the bottom side), 5 nets.

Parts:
C1: 0.1uF; C_Disc_D6_P5
P1, P5: CONN_01X07; Pin_Header_Straight_1x07
P2: DHT22; Pin_Header_Straight_1x03
P3: GY-87; Pin_Header_Straight_1x08
P4, P6: CONN_01X04; Pin_Header_Straight_1x04

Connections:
+BATT: C1.1, P1.2, P2.2, P3.1, P5.1
/DHT/D6: P1.7, P2.1
/SCL: P1.3, P3.4
/SDA: P1.4, P3.5
GND: C1.2, P1.1, P2.3, P3.3, P5.2

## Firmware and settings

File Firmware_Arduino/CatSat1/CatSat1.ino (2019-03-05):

/************************************************************
  SPANISH
  CatSat1.ino
  CatSat 1 - Satelite en Lata Educativo
  Andres Sabas @ Electronic Cats
  Eduardo Contreras @ Electronic Cats
  Original Creation Date: Jul 10, 2016
  https://github.com/ElectronicsCats/CatSat/

  Este ejemplos demuestra el funcionamiento basico de los sensores y funcionalidad
  basica del CatSat 1 Kit Educativo
  http://electroniccats.com

  Especificaciones del entorno de Desarrollo:
  IDE: Arduino 1.8.4
  Plataforma de Hardware:
  Kit CanSat
  - Arduino Mini Pro
  - DHT22
  - GY-87
  - GPS L80


  Este código es beerware si tu me ves ( o cualquier otro miembro de Electronic Cats)
  a nivel local, y tu has encontrado nuestro código útil ,
  por favor comprar una ronda de cervezas!

  Distribuido como; no se da ninguna garantía.
************************************************************/

/************************************************************
  ENGLISH
  CatSat1.ino
  CatSat 1 - Satelite en Lata Educativo
  Andres Sabas @ Electronic Cats
  Original Creation Date: Jal 10, 2016
  https://github.com/ElectronicsCats/CatSat/

  This example demonstrates how to use CatSat 1

  Development environment specifics:
  IDE: Arduino 1.8.4
  Hardware Platform:
  Kit CanSat
  - Arduino Mini Pro
  - DHT22
  - GY-87
  - GPS L80

  This code is beerware; if you see me (or any other Electronic Cats
  member) at the local, and you've found our code helpful,
  please buy us a round!

  Distributed as-is; no warranty is given.

  Library I2CDev and MPU6050
  https://github.com/jrowberg/i2cdevlib

  Library Arduino LoRa
  https://github.com/sandeepmistry/arduino-LoRa
*/

#include <LoRa.h>

#include <Wire.h>
#include <NeoSWSerial.h>

#include <NMEAGPS.h>

#include <MPU6050.h>

#include <Adafruit_Sensor.h>
#include <Adafruit_HMC5883_U.h>
#include <Adafruit_BMP085_U.h>
#include <DHT_U.h>

#define DHTPIN 6 // Pin digital para DHT22
#define DHTTYPE DHT22   // DHT 22  (AM2302)

#define RFM95_CS 10
#define RFM95_RST 9
#define RFM95_INT 2

//Command activation Balloon mode
#define PMTK_SET_NMEA_886_PMTK_FR_MODE  "$PMTK886,3*2B"
// Command turn on GPRMC and GGA
#define PMTK_SET_NMEA_OUTPUT_RMCGGA "$PMTK314,0,1,0,1,0,0,0,0,0,0,0,0,0,0,0,0,0,0,0*28"

//Uncomment for debugging
//#define DEBUG

uint32_t selectBand(int);

/************************************************************
     IMPORTANTE CAMBIAR id_node DEPENDIENDO TU CANSAT
************************************************************/

String id_node = "A1";

/*******************************************************
  Selecciona un canal entre 0 y 12 este debe coincidir
  con el canal de tu satelite
 *******************************************************/
int chan = 12;

// Inicializar DHT sensor.
DHT_Unified dht(DHTPIN, DHTTYPE);

MPU6050 accelgyro;
//Variables de Aceleración y Giroscopio
//Accel and Gyro Vars
int16_t ax, ay, az;
int16_t gx, gy, gz;

String Todo; //String a mandar

NMEAGPS gps;
static gps_fix  fix;
static const int RXPin = 5, TXPin = 6;
static const uint32_t GPSBaud = 9600;
static uint32_t last_rx = 0UL; // The last millis() time a character was
                               // received from GPS.

NeoSWSerial ss(RXPin, TXPin);

/* Assign a unique ID to this sensor at the same time */
Adafruit_HMC5883_Unified mag = Adafruit_HMC5883_Unified(1);

Adafruit_BMP085_Unified bmp = Adafruit_BMP085_Unified(2);

unsigned long previousMillis = 0;


void enviarInfo(String outgoing) {
  LoRa.beginPacket();                   // start packet
  LoRa.print(outgoing);                 // add payload
  LoRa.endPacket();                     // finish packet and send it
  Serial.println("Dato enviado");
}

void ballonModeGPS() {
  bool flag = 0;
  String gpsData = "";
  while (!flag) {
    if ((ss.available())) {
          flag = 1;
          ss.println(PMTK_SET_NMEA_886_PMTK_FR_MODE);
          while (ss.available()) {
            gpsData += (char)ss.read();
          }
          gpsData = "";
          ss.println(PMTK_SET_NMEA_OUTPUT_RMCGGA);
    }
  }
  Serial.println("GPS balloon mode configured");
}


void setup() {
  Serial.begin(115200);
  ss.begin(GPSBaud);
  dht.begin();

  /*****LoRa init****/
  //Re-write pins CS, reset, y IRQ
  LoRa.setPins(RFM95_CS, RFM95_RST, RFM95_INT); // CS, reset, int pin

  if (!LoRa.begin(selectBand(chan))) {           // initialize ratio at 915 MHz
    Serial.println("LoRa init failed. Check your connections.");
    while (true);                       // if failed, do nothing
  }

  LoRa.setTxPower(17); //Set the max transmition power
  LoRa.setSpreadingFactor(10); //Change the SF to get longer distances

  /******************/

  /* Initialise the sensor */
  if (!bmp.begin())
  {
    /* There was a problem detecting the BMP085 ... check your connections */
    Serial.print(F("Ooops, no BMP085 detected ... Check your wiring or I2C ADDR!"));
    while (1);
  }

  accelgyro.initialize();  /// Initialize MPU

  accelgyro.setI2CMasterModeEnabled(false);
  accelgyro.setI2CBypassEnabled(true) ;
  accelgyro.setSleepEnabled(false);

  // Initialise the sensor
  if (!mag.begin())
  {
    // There was a problem detecting the HMC5883 ... check your connections
    Serial.println(F("Ooops, no HMC5883 detected ... Check your wiring!"));
    while (1);
  }
  
  /*
    Activation Balloon mode:
    For high-altitude balloon purpose that the vertical movement will
    have more effect on the position calculation
  */
  ballonModeGPS();
  
  Serial.println(F("CatSat 1 Ready!"));
  Serial.println(F("Fw version 2.0.2"));
}

void loop() {
  while (gps.available( ss )) {
    last_rx = millis();
    fix = gps.read();
    
    readSensors();
    gpsread();
    Serial.println(Todo);
    enviarInfo(Todo);
    Todo = "";
  }
  listenForSomething();
}

bool readSensors(void) {
  Todo += id_node;  //Add id to String
  Todo += ",";
  sensors_event_t event;

  dht.temperature().getEvent(&event);
  if (isnan(event.temperature)) {
    Serial.println(F("Error reading temperature!"));
    Todo += 0;
    Todo += ",";
  }
  else {
#ifdef DEBUG
    Serial.print(F("TemperatureDHT: "));
    Serial.print(event.temperature);
    Serial.println(F(" *C"));
#endif
    Todo += event.temperature;
    Todo += ",";
  }

  dht.humidity().getEvent(&event);
  if (isnan(event.relative_humidity)) {
    Serial.println(F("Error reading humidity!"));
    Todo += 0;
    Todo += ",";
  }
  else {
#ifdef DEBUG
    Serial.print(F("HumidityDHT: "));
    Serial.print(event.relative_humidity);
    Serial.println(F("%"));
#endif
    Todo += event.relative_humidity;
    Todo += ",";
  }

  bmp.getEvent(&event);

  if (event.pressure)
  {
    // Display atmospheric pressue in hPa
#ifdef DEBUG
    Serial.print(F("Pressure:    "));
    Serial.print(event.pressure);
    Serial.println(F(" hPa"));
#endif
    Todo += event.pressure;
    Todo += ",";

    float temperature;
    bmp.getTemperature(&temperature);
    Todo += temperature;
    Todo += ",";

#ifdef DEBUG
    Serial.print(F("Temperature: "));
    Serial.print(temperature);
    Serial.println(F(" C"));
#endif
  }
  else
  {
    Serial.println(F("Sensor error"));
  }


 // mag.getEvent(&event);

  // Display the results (magnetic vector values are in micro-Tesla (uT))
#ifdef DEBUG
  Serial.print(F("Magnetometro:  "));
  Serial.print(F("X: ")); Serial.print(event.magnetic.x); Serial.print(F("  "));
  Serial.print(F("Y: ")); Serial.print(event.magnetic.y); Serial.print(F("  "));
  Serial.print(F("Z: ")); Serial.print(event.magnetic.z); Serial.print(F("  ")); Serial.println(F("uT"));
#endif
  Todo += event.magnetic.x;
  Todo += ",";
  Todo += event.magnetic.y;
  Todo += ",";
  Todo += event.magnetic.z;
  Todo += ",";

  accelgyro.getMotion6(&ax, &ay, &az, &gx, &gy, &gz);
#ifdef DEBUG
  Serial.print(F("Acelerometro "));
  Serial.print(F("X:")); Serial.print(ax); Serial.print("\t");
  Serial.print(F("Y:")); Serial.print(ay); Serial.print("\t");
  Serial.print(F("Z:")); Serial.print(az); Serial.print("\n");
  Serial.print(F("Giroscopio "));
  Serial.print(F("X:")); Serial.print(gx); Serial.print("\t");
  Serial.print(F("X:")); Serial.print(gy); Serial.print("\t");
  Serial.print(F("X:")); Serial.println(gz); Serial.print("\n");
#endif
  Todo += ax;
  Todo += ",";
  Todo += ay;
  Todo += ",";
  Todo += az;
  Todo += ",";
  Todo += gx;
  Todo += ",";
  Todo += gy;
  Todo += ",";
  Todo += gz;
  Todo += ",";
}

void gpsread(void) {
  Serial.print(F("Location: "));
  if (fix.valid.location)
  {
    Todo += String(fix.latitude(), 6);
    Todo += ",";
    Todo += String(fix.longitude(), 6);
    Todo += ",";
    Todo += String(fix.altitude(), 6);
    Todo += ",";
    Todo += String(fix.speed_kph(), 6);
    Serial.print(fix.latitude(), 6);
    Serial.print(F(","));
    Serial.print(fix.longitude(), 6);
  }
  else
  {
    Todo += "0";
    Todo += ",";
    Todo += "0";
    Todo += ",";
    Todo += "0";
    Todo += ",";
    Todo += "0";
    Serial.print(F("INVALID"));
  }

  Serial.print(F("  Date/Time: "));
  if (fix.valid.date)
  {
    Serial.print(fix.dateTime.month);
    Serial.print(F("/"));
    Serial.print(fix.dateTime.day);
    Serial.print(F("/"));
    Serial.print(fix.dateTime.year);
  }
  else
  {
    Serial.print(F("INVALID"));
  }

  Serial.print(F(""));
  if (fix.valid.date)
  {
    if (fix.dateTime.hours < 10) Serial.print(F("0"));
    Serial.print(fix.dateTime.hours);
    Serial.print(F(":"));
    if (fix.dateTime.minutes < 10) Serial.print(F("0"));
    Serial.print(fix.dateTime.minutes);
    Serial.print(F(":"));
    if (fix.dateTime.seconds < 10) Serial.print(F("0"));
    Serial.print(fix.dateTime.seconds);
    Serial.print(F("."));
  }
  else
  {
    Serial.print(F("INVALID"));
  }

  Serial.println();
}

uint32_t selectBand(int a) {
  switch (a) {
    case 0:
      return 903080000; //903.08 Mhz
      break;
    case 1:
      return 905240000; //905.24
      break;
    case 2:
      return 907400000; //907.40
      break;
    case 3:
      return 909560000; //909.56
      break;
    case 4:
      return 911720000; //911.72
      break;
    case 5:
      return 913880000; //913.88
      break;
    case 6:
      return 916040000; //916.04
      break;
    case 7:
      return 918200000; // 918.20
      break;
    case 8:
      return 920360000; //920.36
      break;
    case 9:
      return 922520000; //922.52
      break;
    case 10:
      return 924680000; //924.68
      break;
    case 11:
      return 926840000; //926.84
      break;
    case 12:
      return 915000000; //915
      break;
  }
}

//----------------------------------------------------------------
//  Listen to see if the GPS device is correctly 
//  connected and functioning.

static void listenForSomething()
{
  uint32_t current_ms  =  millis();
  uint32_t ms_since_last_rx   = current_ms - last_rx;
    if ((ms_since_last_rx >7000)) {
      Serial.println( F("\nCheck GPS device and/or connections.  No data received.\n") );
 }
}

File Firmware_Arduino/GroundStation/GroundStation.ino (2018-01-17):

/************************************************************
SPANISH
EarthStation.ino
EarthStation - Estacion Terrena para CatSat
Eduardo Contreras @ Electronic Cats
Original Creation Date: Jul 14, 2016
https://github.com/ElectronicsCats/CatSat/

Este ejemplo demuestra el funcionamiento basico de la estacion terrena
la cual filtra los Satelites

http://electroniccats.com

Especificaciones del entorno de Desarrollo:
  IDE: Arduino 1.6.11
  Plataforma de Hardware:
  Estacion terrena CanSat
  - Arduino Mini Pro
  - RFM95


Este código es beerware si tu me ves ( o cualquier otro miembro de Electronic Cats) 
a nivel local, y tu has encontrado nuestro código útil ,
por favor comprar una ronda de cervezas!

Distribuido como; no se da ninguna garantía.
************************************************************/

/************************************************************
ENGLISH
EarthStation.ino
EarthStation - Earth-Station for CatSat
Eduardo contreras @ Electronic Cats
Original Creation Date: Jal 14, 2016
https://github.com/ElectronicsCats/CatSat/

This example demonstrates how to use the earth-station for CatSat

Development environment specifics:
  IDE: Arduino 1.6.8
  Hardware Platform:
  Kit CanSat
  - Arduino Mini Pro
  - RFM95
  

This code is beerware; if you see me (or any other Electronic Cats 
member) at the local, and you've found our code helpful, 
please buy us a round!

Distributed as-is; no warranty is given.

Library LoRa Radio
http://www.airspayce.com/mikem/arduino/RadioHead/index.html
**********************************************************
*IMPORTANTE CAMBIA TU ID DEPENDIENDO DE TU CANSAT         *
**********************************************************/

#include <SPI.h>
#include <RH_RF95.h>

/*******************************************************  
 *Selecciona un canal entre 0 y 12 este debe coincidir *
 *con el canal de tu satelite                          *
 *******************************************************/
int channel = 12;

String ID = "A1";

float chann;
String buff;

RH_RF95 rf95(10, 2);
 
float selectBand(int);
 
void setup() 
{     
  pinMode(9, OUTPUT);
  digitalWrite(9, HIGH);
 
  while (!Serial);
  Serial.begin(9600);
  delay(100);
  
  // manual reset
  digitalWrite(9, LOW);
  delay(10);
  digitalWrite(9, HIGH);
  delay(10);
 
  while (!rf95.init()) {
    Serial.println("LoRa radio init failed");
    while (1);
  }
  chann = selectBand(channel);
  if (!rf95.setFrequency(chann)) {
    while (1);
  }
  rf95.setTxPower(23, false);
}
 
void loop()
{
  
  if (rf95.available())
  {
    //Recibio mensaje completo  
    uint8_t buf[RH_RF95_MAX_MESSAGE_LEN];
    uint8_t len = sizeof(buf);
    
    if (rf95.recv(buf, &len))
    { 
      // String buff = (char*)buf;
       //Serial.println(buff);
      String buff = (char*)buf;
      buff += ",";
      buff += String(rf95.lastRssi());
    // Serial.println(rf95.lastRssi(), DEC);  
       if(buff.startsWith(ID))
        {
          Serial.println(buff);
          }
      }
    else
      {
      Serial.println(F("Receive failed"));
       }
  }
}

float selectBand(int a)
{    
  switch(a){ 
    case 0:
    return 903.08;
  break;
    case 1:
    return 905.24;
  break;
    case 2:
    return 907.40;
  break;
    case 3:
    return 909.56;
  break;
    case 4:
    return 911.72;
  break;
    case 5:
    return 913.88;
  break;
    case 6:
    return 916.04;
  break;
    case 7:
    return 918.20;
  break;
    case 8:
    return 920.36;
  break;
    case 9:
    return 922.52;
  break;
    case 10:
    return 924.68;
  break;
    case 11:
    return 926.84;
  break;
    case 12:
    return 915;
  break;
  }
  
 }

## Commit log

2016-07-19 Commented prints unnecessary
2016-07-25 Added Schematic
    Initial Schematic in KiCad
    [CatSat.kicad_pcb, CatSat.sch, Sensors.sch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]
2016-07-27 Schematic v0.2
    Added IC and wiring
    [CatSat.sch, Sensors.sch, Telemetrysch.sch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]
2016-07-29 Fix arduino mini pro pin 6 bug, added capacitors
    [CatSat.sch, Sensors.sch, Telemetrysch.sch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]
2016-07-29 Added PCB's
    [_saved_control.sch, control.kicad_pcb, sensores.kicad_pcb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]
2016-07-29 Added library with footprints
2016-08-01 Finished telemtry PCB
    [CatSat.kicad_pcb, Sensors.sch, Telemetrysch.sch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]
2016-08-01 Fix PCBs
    [_saved_control.sch, control.kicad_pcb, sensores.kicad_pcb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]
2016-08-01 Fix PCB sensores
    [sensores.kicad_pcb]
2016-08-01 Add logo ElectronicCats
    [control.kicad_pcb, sensores.kicad_pcb, telemetria.kicad_pcb]
2016-08-01 Fix bug GND of GY-87
    [control.kicad_pcb, sensores.kicad_pcb]
2016-08-02 PCB final
    [Sensors.sch, Telemetrysch.sch, control.kicad_pcb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]
2016-08-02 Added earth station
    [earth station.kicad_pcb, earth station.sch]
2016-08-03 Fix details
    [control.kicad_pcb, sensores.kicad_pcb, telemetria.kicad_pcb]
2016-08-03 Add logos
    [earth station.kicad_pcb]
2016-08-03 Fix sma connector and pads
    [_saved_earth station.sch, earth station.kicad_pcb]
2016-08-04 Update logos and fix pads
    [earth station.kicad_pcb]
2016-08-06 Earth_station v1.2
    [_saved_earth station.sch, earth station.kicad_pcb, earth station.sch]
2016-08-10 Fix earth station and ID to the frimware
    [earth station.kicad_pcb]
2016-08-11 Added schematic PDF
    [CatSat.sch, Sensors.sch, Telemetrysch.sch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]
2016-08-11 Fix Source Track
    [control.kicad_pcb, control.sch]
2016-08-11 Update DHT Pin
2016-08-12 added logo to schematic
    [CatSat.sch, Sensors.sch, Telemetrysch.sch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]
2016-08-20 Earth_station Fix
    Capacitor changed
    [earth station.kicad_pcb]
2016-08-23 Added Logos
    [earth station.kicad_pcb]
2016-08-25 Fix tracks and vias width
    [earth station.kicad_pcb]
2016-08-25 Added holes
    [earth station.kicad_pcb]
2016-08-26 Fix Wire
    [earth station.kicad_pcb]
2016-08-27 Fix design 0.2V
    [earth station.kicad_pcb]
2016-08-27 Fix 0.3v
    [earth station.kicad_pcb, earth station.sch]
2016-08-27 Move Logos
    [earth station.kicad_pcb]
2016-08-27 Via fix again
    [earth station.kicad_pcb]
2016-08-27 Toc Fix Ignacio
    [earth station.kicad_pcb]
2016-09-03 Add PDF's
    [CatSat.sch, Sensors.sch, Telemetrysch.sch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]
2016-09-07 Fix paths
    [earth station.kicad_pcb, earth station.sch]
2016-09-13 Added Manual Camera
2016-10-16 Move Path Footprint
2016-10-16 New Path Communication
    [CommunicationBoard.kicad_pcb, CommunicationBoard.sch]
2016-10-16 New path MainBoard
    [MainBoard.kicad_pcb, MainBoard.sch]
2016-10-16 New Path Sensor Board
    [SensorBoard.kicad_pcb, SensorBoard.sch]
2016-10-16 BackOldversion Path and name boards
    [CatSat.kicad_pcb, CatSat.sch, Sensors.sch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]
2016-10-16 Remove folder PCBs
2016-10-16 Update Schematic MainBoard
    [MainBoard.sch]
2016-10-16 Update Schematic SensorBoard
    [SensorBoard.sch]
2016-10-16 Update Schemcatic Communication
    [CommunicationBoard.sch]
2016-10-16 Update Names in Schematic
    [MainBoard.sch, SensorBoard.sch]
2016-10-16 Update referencePCB for schematic MainBoard
    [MainBoard.kicad_pcb]
2016-10-16 Update PCB referenceschematic SensorBoard
    [SensorBoard.kicad_pcb]
2016-10-16 Update PCB with Schematic
    [CommunicationBoard.kicad_pcb]
2016-10-18 Update PCB footprints MainBoard
    [MainBoard.kicad_pcb]
2016-10-18 Update PCB via Sensor Board
    [SensorBoard.kicad_pcb]
2016-10-18 Update PCB via GPS & Telecomm board
    [CommunicationBoard.kicad_pcb]
2016-10-18 Correction pad, via and logo
    [MainBoard.kicad_pcb]
2016-10-18 fix via data dht22
    [SensorBoard.kicad_pcb]
2016-10-18 Fix Ground station <3
    [GroundStation.kicad_pcb, GroundStation.sch]
2016-10-18 Add label's Communication board
    [CommunicationBoard.kicad_pcb]
2016-10-18 Added labels pinout SensorBoard
    [SensorBoard.kicad_pcb]
2016-10-18 Add 1.1v
    [CommunicationBoard.kicad_pcb]
2016-10-18 Fix GroundStation Firmware
    Rename File and folder
    [GroundStation.ino]
2016-10-18 Added label Main Board
    [MainBoard.kicad_pcb]
2016-10-18 Fix Label Communication
    [CommunicationBoard.kicad_pcb]
2016-10-18 Add extra I/O pins Ground station
    [GroundStation.kicad_pcb, GroundStation.sch]
2016-10-18 Fix Labels GroundStation
    [GroundStation.kicad_pcb]
2016-10-18 Added Schematic PDFs
2016-10-18 Added images of boards
2016-10-25 Correction Main Board
    [MainBoard.kicad_pcb]
2016-10-25 Correction GroundBoard
    [GroundStation.kicad_pcb]
2016-12-15 Correction tracks
    [GroundStation.kicad_pcb, MainBoard.kicad_pcb, SensorBoard.kicad_pcb]
2016-12-29 Add larger holes
    [CommunicationBoard.kicad_pcb, MainBoard.kicad_pcb, SensorBoard.kicad_pcb]
2017-01-05 Remove pines FTDI Arduino mini
    [MainBoard.kicad_pcb]
2017-06-06 add LM2596 to kicad
2018-10-02 Add new payload
    Added folder for new payload and project
    [breakout-2018-10-02-18-22-51.sch, breakout.kicad_pcb, breakout.sch]
2018-10-26 add footprint
    [breakout.kicad_pcb]
2018-10-31 Update payload
    [breakout.kicad_pcb, breakout.sch]
2019-01-16 change to arduino lora
2019-01-16 ground station migrate
2019-01-17 change led to builtin
2019-01-18 update version arduino
2019-01-25 Add Accelerometer function
2019-01-26 fix gps without gps flag, remove temporal millis function
    [CatSat1.ino]
2019-01-27 revert commit comment mag.getevent
    [CatSat1.ino]
2019-01-28 Add altitude and velocity by GPS
2019-01-28 Fix bug lora frequency
    [CatSat1.ino]
2019-01-28 erase \n to add the RSSi at ground station
2019-02-12 Add Case for 3D printing
    [base.STL, camarasuport.STL, satelite2.2.STL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]
2019-02-26 fix mode gps ballon
    [CatSat1.ino]
2019-03-05 Patch magnetometer library error
    [CatSat1.ino]
